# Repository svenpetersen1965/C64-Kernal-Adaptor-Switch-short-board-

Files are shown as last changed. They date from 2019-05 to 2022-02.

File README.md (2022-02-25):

# C64-Kernal-Adapter-Switch-short-board-
This is a Kernal Adapter/Switch for the Commodore C64, ASSY250469 (short board). 
Since the BASIC is stored in the same ROM, some circuit is required to allow a stable access to BASIC, while the Kernal can be selected.
The kernal selection can be configured with jumpers, a switch or even with a micro controller. +5V are provided on the pin header for this purpose.

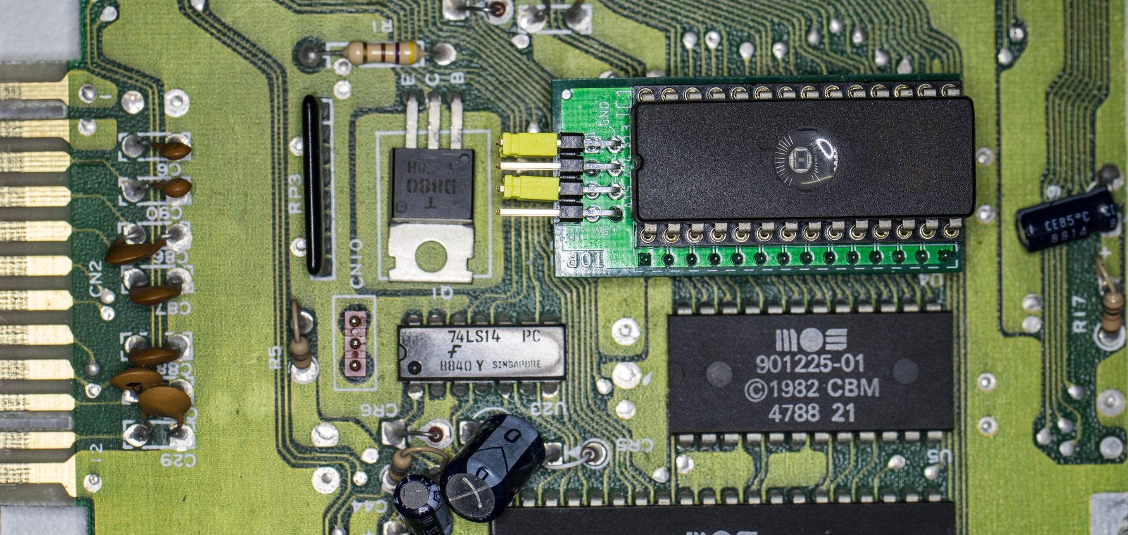
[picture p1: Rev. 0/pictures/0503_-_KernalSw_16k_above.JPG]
C64 kernal adapter/switch for ASSY250469


This development was inspired by Adrian Black's youtube video <a href="https://youtu.be/GPq5xnJRw2w">How-To: C64 Arduino based Restore Key/Four Kernal Switcher/Hard Reset</a>
# Rev. 2
Rev. 2 provides an optional pin heaer  with the address bit A5 and A8 for stereo SID applications
# BOM Calculation
The component prices of BOM v0.0 were summed up. The total is  4.88€, which does not include any shipping fees.

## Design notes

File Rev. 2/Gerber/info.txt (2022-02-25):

      
       Board: C64_KernalSw_16k
       Rev.:  2
  
       Files:
       ======
  
       All Gerber files are generated in extended gerber format (RS274X)
       *.TOP        : Film top copper
       *.BOT        :  -"- bottom copper
       *.STC        :  -"- top soldermask 
       *.STS        :  -"- bottom soldermask
       *.PLC        :  -"- silk screen top
       *.PLS        :  -"- silk screen bottom
       *.CRC        :  -"- cream top
       *.DK         : Drills plated Through (Excellon)
       *.NDK        : Drills not plated Through (Excellon)
       *.OUT        : Board outline

       Board Size:
       ===========
       Length     :   45.0 mm
       Width      :   22.0 mm
       Thickness  :   1.6 mm
       Material   :   FR 4
       Copper     :   35 um
       Surface    :   HASL
       
       Remarks:
       ========

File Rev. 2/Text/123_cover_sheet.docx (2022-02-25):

Project Documentation

C64 Kernal Adapter/Switch (Short Board)

Project number: 123

Revision: 2

Date: 14.11.2021

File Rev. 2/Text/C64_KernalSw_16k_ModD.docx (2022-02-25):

C64 Kernal Adapter/Switch (Short Board) Rev. 2

Module Description

# Introduction

The board serves for adapting the BASIC/KERNAL ROM U4 (type 23128b) to a 27C512 (or 27C256 or 27C128) EPROM. The pin out of both ICs are slightly different and need adaptation. Furthermore, it allows to access (up to 7) different kernals, which can be selected via the pin-header on the module.

This pin-header is connected in a way, that the selection can either be accomplished with standard 2.54mm jumper bridges, DIP-switches, hex-encoding switches or a microcontroller like an Arduino etc.

Signal | Pin | Pin | Signal
A13 | 1 | 2 | GND
A14 | 3 | 4 | GND
A15 | 5 | 6 | GND
+5V | 7 | 8 | n.c.

Table 1: Jumper (JP1) for Bank Selection

The +5V pins are to provide supply voltage to a microcontroller.

# Dimensions

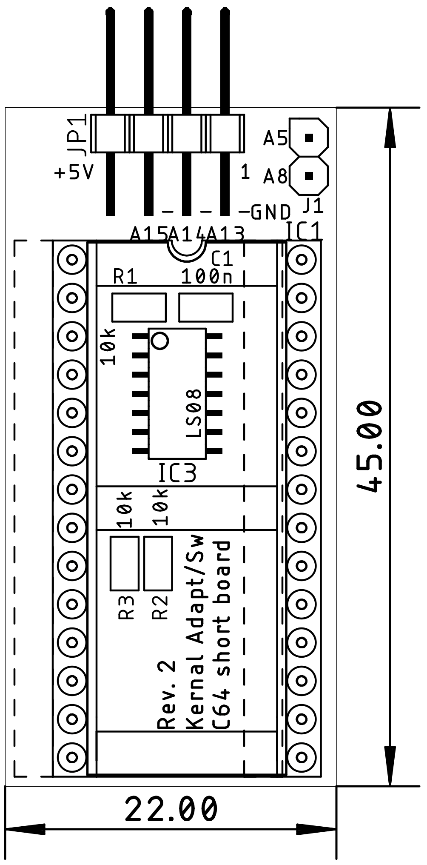
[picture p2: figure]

Figure 1: Kernal Adapter/Switch

# Function

The short board (ASSY 250469) stores the BASIC and the KERNAL in the same ROM. Long boards (all earlier ASSYs) have a separate ROM for BASIC.

The BASIC is located in the C64’s address space between 0xA000 - 0xBFFF, the KERNAL is located between 0xE000 – 0xFFFF. The highest three address bits have to be taken care to distinguish between BASIC and KERNAL.

Hex Digit | Binary [A15…A12] | ROM
AHEX | HLHL | BASIC
BHEX | HLHH | BASIC
EHEX | HHHL | KERNAL
FHEX | HHHH | KERNAL

Table 2: Encoding of the address bits

A15, A13 and A12 are encoded the same was for both the BASIC and the KERNAL. A14 makes the difference. Consulting the schematic of ASSY250469 (Document 252312), A14 of the CPU address bus is connected to A13 (pin 26) of the 16k ROM (U4/23128B). A LOW on A14 will select the lower 8k, a HIGH will select the higher 8k.

This has to be taken care of on the EPROM adapter. A LOW on A13 (which is connected to A14 of the CPU) has to select the lowest (BASIC) 8k block, a HIGH is addressing the (KERNAL) 8k memory block, which is selected by the jumper JP1. The trick is done with three AND gates (IC3). The outputs are connected to A13 … A15 of the EPROM. One input of each one is connected to pin 26 of the socket U4. In case this is LOW (BASIC selected) the output of all three gates is LOW, too. The lowest 8k memory block of the EPROM is selected. In case pin 26 is HIGH, the configuration set on JP1 appears at the output of the AND gates. This way, the selected 8k memory block of the EPROM is addressed.

# Bank Selection

The desired KERNAL is selected at JP1. For the pinout refer to Table 1. The jumper is installed (vertically) in a way, that it connects the address line with the GND potential.

A15 | A14 | A13 | 8k Block | Addr. Offset
set | set | set | illegal | 0x0000
set | set | open | #1 | 0x2000
set | open | set | #2 | 0x4000
set | open | open | #3 | 0x6000
open | set | set | #4 | 0x8000
open | set | open | #5 | 0xA000
open | open | set | #6 | 0xC000
open | open | open | #7 | 0xE000

Table 3: Selection of EPROM memory blocks

A set jumper corresponds to a LOW level (binary 0), an open jumper to a HIGH level. Do not confuse the C64 memory address and the EPROM memory address. They have the address Bit A0 to A12 in common, but the rest is different. Each of the 8k blocks appears between address $E000 and $FFFF of the C64. The setting marked illegal selects the lowest 8k, which are reserved for the BASIC. Do not use more than two jumpers to prevent this.

# Sources for BASIC and KERNAL

The content of the BASIC ROM and the KERNAL ROM can be found here:

http://www.zimmers.net/anonftp/pub/cbm/firmware/computers/c64/index.html (64c.251913-01.bin (http://www.zimmers.net/anonftp/pub/cbm/firmware/computers/c64/64c.251913-01.bin))

This file includes the BASIC and the original KERNAL and have to be loaded to the lowest 16k of the EPROM. In case it is not desired to load the original KERNAL to 8k-Block #1, this memory block can be overwritten.

Separate BASIC and KERNAL ROMs and Scandinavian KERNAL ROMs can be found at the URL mentioned before or can alternatively be obtained from the Emulator Software VICE (C64/basic and C64/kernal).

Alternative kernals can be found elsewhere on internet. A reliable source is

https://csdb.dk/

The popular JiffyDOS is still a commercial product and can be acquired for little money from

http://www.go4retro.com/

JaffyDOS is a patch for JiffyDOS. The patch program can be obtained from World of Jani:

http://blog.worldofjani.com

# Setting up an EPROM image

Combining the desired ROM (*.bin) files to one programming image works with the software of the programmer. This might a different with different model. Here it is demonstrated using the popular TL866. In case the programmer software does not provide the function, a Hex Editor like HxD will do the job.

First, the BASIC ROM has to be loaded into the buffer. This works like always:

File → Open → Select the BASIC ROM

Use default file load options (Figure 2):

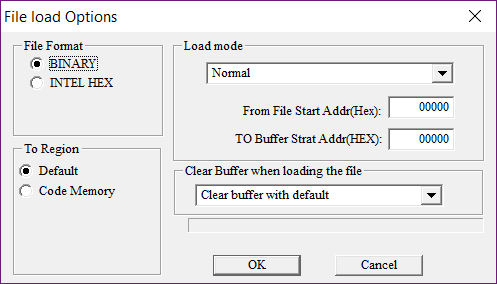
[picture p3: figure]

Figure 2: Default load options, clear buffer with default

Now the BASIC is loaded. It will occupy the addresses 0000 – 1FFF.

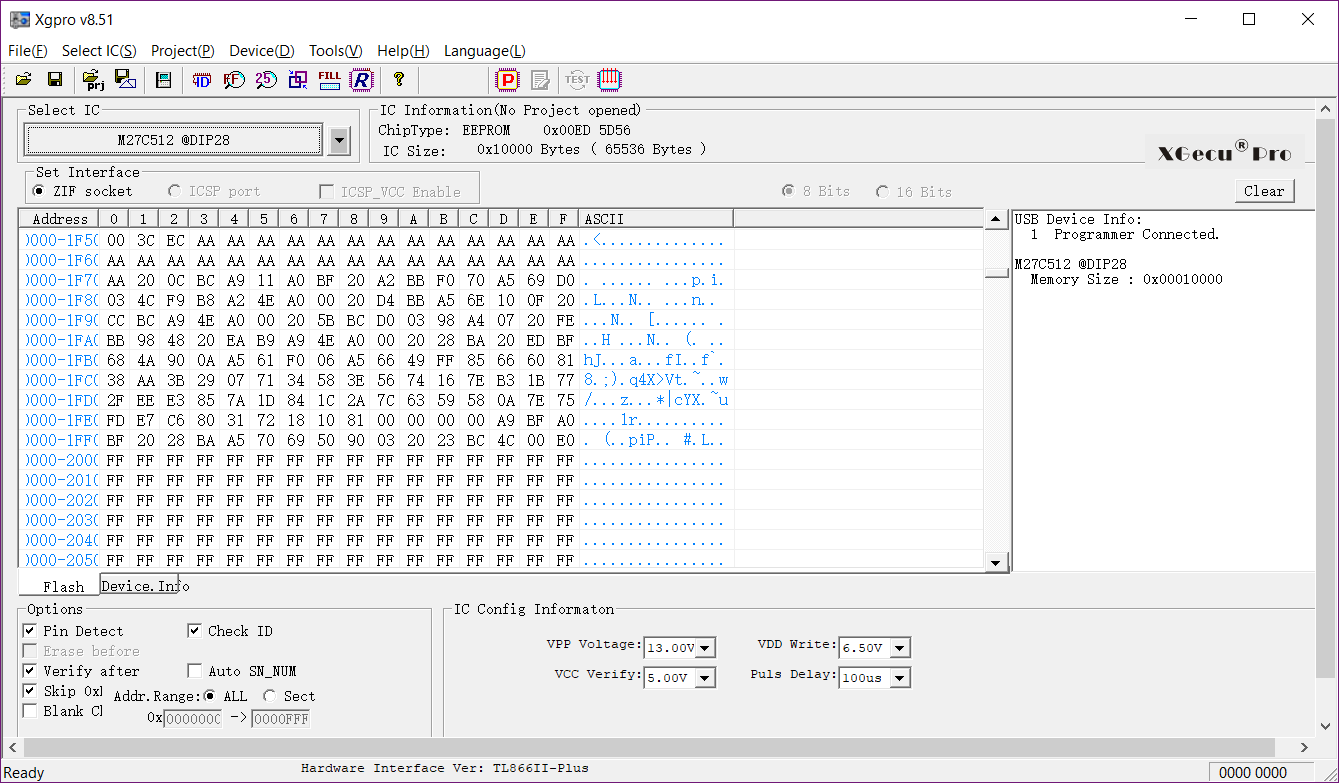
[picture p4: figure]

Figure 3: Buffer content after BASIC was loaded

The buffer above 1FFF is still empty (filled with FF, Figure 3).

The KERNAL has to be loaded to the next free 8k memory block in the buffer. Please refer to Table 3. Further, it is important, not to clear the buffer. Otherwise, the BASIC will be lost and the EPROM will not work. Refer to Figure 4.

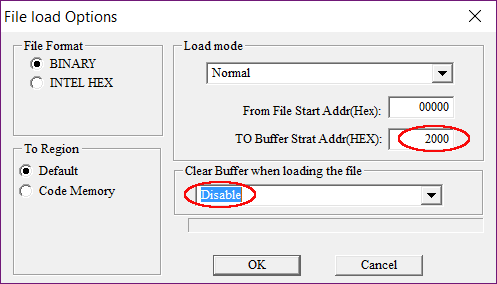
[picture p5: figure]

Figure 4: Load options for the first KERNAL

Clear Buffer when loading file is disabled, the address for the first kernal is 2000HEX

Repeat this procedure with the appropriate buffer/EPROM address, until all desired kernals are in the buffer. Store the buffer for later use, insert a blank EPROM and program it. Insert it in the Kernal Adapter/Switch.

# Adding More Kernals to an Already programmed EPROM

In case the unused 8k memory slots of the EPROM are filled with FF, it is still possible to program additional kernel images without erasing them before. FF is the content of an empty byte in an EPROM. It is possible to alter such a byte to every other byte content. Before the new memory is written, the prior content can be read into the program buffer, then a free 8k slot is determined and the kernel is loaded into that slot. Refer to chapter “Setting up an EPROM image”. Now, the buffer content can be programmed. It is possible to program the complete buffer, the bytes already programmed will (usually) not be corrupted and after programming, the EPROM will verify ok.

# Installation

Possibly, the BASIC/Kernal ROM (U4) has to be unsoldered and a socket (preferably round pin precision contacts) has to be installed, before the Kernal Adapter/Switch can be installed on ASSY250469. The notch of the EPROM is pointing towards the user port, when installed properly (Figure 5).

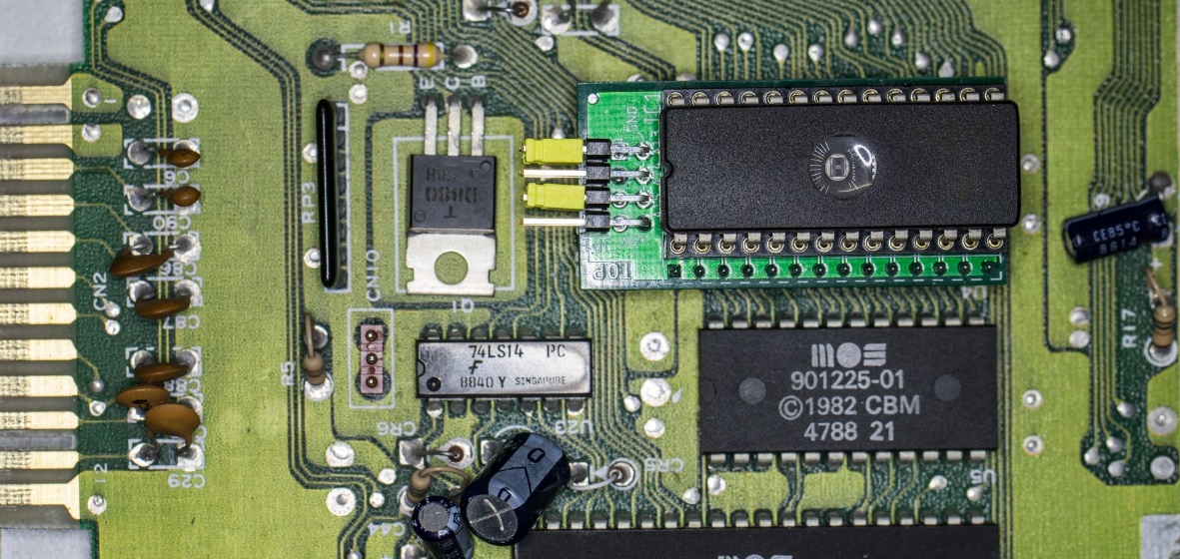
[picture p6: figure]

Figure 5: Installation of the Kernal Adapter/Switch

Usually, the board fits above the components placed next to U4, maybe those have to be bent backwards a bit. Prevent that the resistor touches the pin header of the adapter under all circumstances.

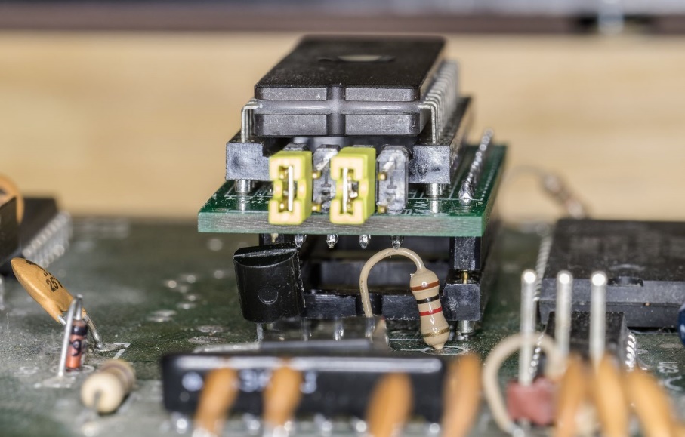
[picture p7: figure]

Figure 6: Parts under the adapter board

# Compatibility of EPROMs

It is recommended to use 27C512 EPROMs only. The smaller EPROM Types 27C256 and 27C128 might conflict with accessing the BASIC 8k slot. The unused address signals will be tied LOW while this access. This means, that Vpp will be approximately 0V and /PGM will be low. This is a not recommended setting.

27C128
| 27C256
| | 27C512
| | | SOCKET
Vpp | Vpp | A15 | 1 | A15 | VCC | 28 | VCC | VCC | VCC
A12 | A12 | A12 | 2 | A12 | A14 | 27 | A14 | A14 | /PGM
A7 | A7 | A7 | 3 | A7 | A13 | 26 | A13 | A13 | A13
A6 | A6 | A6 | 4 | A6 | A8 | 25 | A8 | A8 | A8
A5 | A5 | A5 | 5 | A5 | A9 | 24 | A9 | A9 | A9
A4 | A4 | A4 | 6 | A4 | A11 | 23 | A11 | A11 | A11
A3 | A3 | A3 | 7 | A3 | /OE | 22 | /G/Vpp | /G | /G
A2 | A2 | A2 | 8 | A2 | A10 | 21 | A10 | A10 | A10
A1 | A1 | A1 | 9 | A1 | GND | 20 | /E | /E | /E
A0 | A0 | A0 | 10 | A0 | D7 | 19 | D7 | D7 | D7
D0 | D0 | D0 | 11 | D0 | D6 | 18 | D6 | D6 | D6
D1 | D1 | D1 | 12 | D1 | D5 | 17 | D5 | D5 | D5
D2 | D2 | D2 | 13 | D2 | D4 | 16 | D4 | D4 | D4
GND | GND | GND | 14 | GND | D3 | 15 | D3 | D3 | D3

Table 4: EPROM pin compatibility

# Startup and Trouble shooting

Before you insert the Kernal Adaptor/Switch into the socket of U4, you should make sure, that there are no fatal failures on it. In the worst case, it will produce a short circuit.

- Check the solder joints on the solder side
- Check the orientation of the socket. The notch is oriented to the side, where the jumper is located
- Make sure, that no jumper is installed horizontally. This could connect GND and VCC, which is a short circuit.
- After inserting the EPROM, check if the notch is at the same side like the notch of the socket. Check all pins are properly seated in the socket and not bent inwards or outwards.

After all these points are correct, nothing really bad can happen to your C64 anymore. If you get a black screen you only have a configuration problem.

- Did you program the EPROM with a proper *.bin file? BASIC and one or more kernals? Maybe check the buffer content of your programmer software again.
- Did you set the address bits A13…A15 correctly? A set (closed) jumper means LOW
- You must not set all jumpers. This would put the BASIC in place of the Kernal, which will not work.

# Revision History

## Rev. 0

- Fully working prototype

## Rev. 1

- The shape of the solder-pads of JP1 was changed to enable bridging. Pin 10 is not connected to +5V anymore.

## Rev. 2

- J1 provides A8 and A5 for stereo SID applications

C64_KernalSw_16k_ModD.docx 25.02.2022 10:36 Drafted by Sven Petersen Page 2 of 2 Doc.-No.: 123-6-01-02

C64_KernalSw_16k_ModD.docx 25.02.2022 10:36 Drafted by Sven Petersen Page 1 of 1 Doc.-No.: 123-6-01-00

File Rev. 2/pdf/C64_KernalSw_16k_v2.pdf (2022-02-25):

# Project Documentation

## C64 Kernal Adapter/Switch (Short Board)

## Project number: 123

## Revision: 2

## Date: 14.11.2021

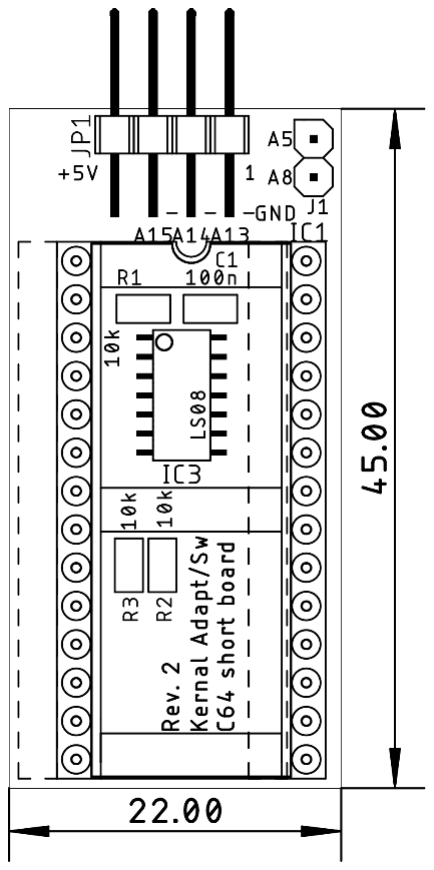
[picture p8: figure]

C64_KernalSw_16k_ModD.docx | | 25.02.2022 10:36
Drafted by Sven Petersen | Page 1 of 7 | Doc.-No.: 123-6-01-02

### C64 Kernal Adapter/Switch (Short Board) Rev. 2

### Module Description

## Introduction

The board serves for adapting the BASIC/KERNAL ROM U4 (type 23128b) to a 27C512 (or 27C256 or 27C128) EPROM. The pin out of both ICs are slightly different and need adaptation. Furthermore, it allows to access (up to 7) different kernals, which can be selected via the pin-header on the module.

This pin-header is connected in a way, that the selection can either be accomplished with standard 2.54mm jumper bridges, DIP-switches, hex-encoding switches or a microcontroller like an Arduino etc.

Signal Pin | Pin Signal
A13 | 1 | 2 | GND
A14 | 3 | 4 | GND
A15 | 5 | 6 | GND
+5V | 7 | 8 | n.c.
Table 1: Jumper (JP1) for Bank Selection

The +5V pins are to provide supply voltage to a microcontroller.

## Dimensions

Figure 1: Kernal Adapter/Switch

## Function

The short board (ASSY 250469) stores the BASIC and the KERNAL in the same ROM. Long boards (all earlier ASSYs) have a separate ROM for BASIC.

C64_KernalSw_16k_ModD.docx | | 25.02.2022 10:36
Drafted by Sven Petersen | Page 2 of 7 | Doc.-No.: 123-6-01-02

### The BASIC is located in the C64’s address space between 0xA000 - 0xBFFF, the KERNAL is

located between 0xE000 – 0xFFFF. The highest three address bits have to be taken care to distinguish between BASIC and KERNAL.
Hex Digit | Binary [A15…A12] ROM
AHEX | HLHL | BASIC
BHEX | HLHH | BASIC
EHEX | HHHL | KERNAL
FHEX | HHHH | KERNAL
Table 2: Encoding of the address bits

A15, A13 and A12 are encoded the same was for both the BASIC and the KERNAL. A14 makes the difference. Consulting the schematic of ASSY250469 (Document 252312), A14 of the CPU address bus is connected to A13 (pin 26) of the 16k ROM (U4/23128B). A LOW on A14 will select the lower 8k, a HIGH will select the higher 8k.

This has to be taken care of on the EPROM adapter. A LOW on A13 (which is connected to A14 of the CPU) has to select the lowest (BASIC) 8k block, a HIGH is addressing the (KERNAL) 8k memory block, which is selected by the jumper JP1. The trick is done with three AND gates (IC3). The
outputs are connected to A13 … A15 of the EPROM. One input of each one is connected to pin
26 of the socket U4. In case this is LOW (BASIC selected) the output of all three gates is LOW, too. The lowest 8k memory block of the EPROM is selected. In case pin 26 is HIGH, the configuration set on JP1 appears at the output of the AND gates. This way, the selected 8k memory block of the EPROM is addressed.

## Bank Selection

The desired KERNAL is selected at JP1. For the pinout refer to Table 1. The jumper is installed (vertically) in a way, that it connects the address line with the GND potential.

A15 | A14 | A13 | 8k Block | Addr. Offset
set | set | set | illegal | 0x0000
set | set | open | #1 | 0x2000
set | open | set | #2 | 0x4000
set | open | open | #3 | 0x6000
open | set | set | #4 | 0x8000
open | set | open | #5 | 0xA000
open | open | set | #6 | 0xC000
open | open | open | #7 | 0xE000
Table 3: Selection of EPROM memory blocks

A set jumper corresponds to a LOW level (binary 0), an open jumper to a HIGH level. Do not confuse the C64 memory address and the EPROM memory address. They have the address Bit A0 to A12 in common, but the rest is different. Each of the 8k blocks appears between address $E000 and $FFFF of the C64. The setting marked illegal selects the lowest 8k, which are reserved for the BASIC. Do not use more than two jumpers to prevent this.

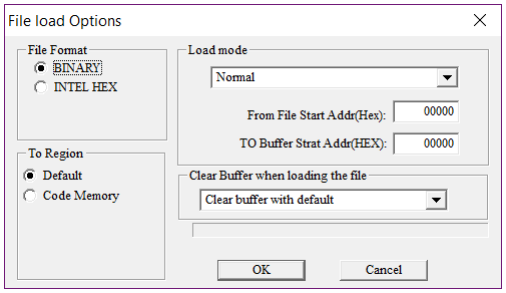
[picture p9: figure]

C64_KernalSw_16k_ModD.docx | | 25.02.2022 10:36
Drafted by Sven Petersen | Page 3 of 7 | Doc.-No.: 123-6-01-02

## Sources for BASIC and KERNAL

The content of the BASIC ROM and the KERNAL ROM can be found here:

http://www.zimmers.net/anonftp/pub/cbm/firmware/computers/c64/index.html (64c.251913-01.bin) (http://www.zimmers.net/anonftp/pub/cbm/firmware/computers/c64/64c.251913-01.bin)

This file includes the BASIC and the original KERNAL and have to be loaded to the lowest 16k of the EPROM. In case it is not desired to load the original KERNAL to 8k-Block #1, this memory block can be overwritten.

Separate BASIC and KERNAL ROMs and Scandinavian KERNAL ROMs can be found at the URL mentioned before or can alternatively be obtained from the Emulator Software VICE (C64/basic and C64/kernal).

Alternative kernals can be found elsewhere on internet. A reliable source is

https://csdb.dk/

The popular JiffyDOS is still a commercial product and can be acquired for little money from

http://www.go4retro.com/

JaffyDOS is a patch for JiffyDOS. The patch program can be obtained from World of Jani:

http://blog.worldofjani.com

## Setting up an EPROM image

Combining the desired ROM (*.bin) files to one programming image works with the software of the programmer. This might a different with different model. Here it is demonstrated using the popular TL866. In case the programmer software does not provide the function, a Hex Editor like HxD will do the job.

First, the BASIC ROM has to be loaded into the buffer. This works like always:

File → Open → Select the BASIC ROM

Use default file load options (Figure 2):

Figure 2: Default load options, clear buffer with default
Now the BASIC is loaded. It will occupy the addresses 0000 – 1FFF.

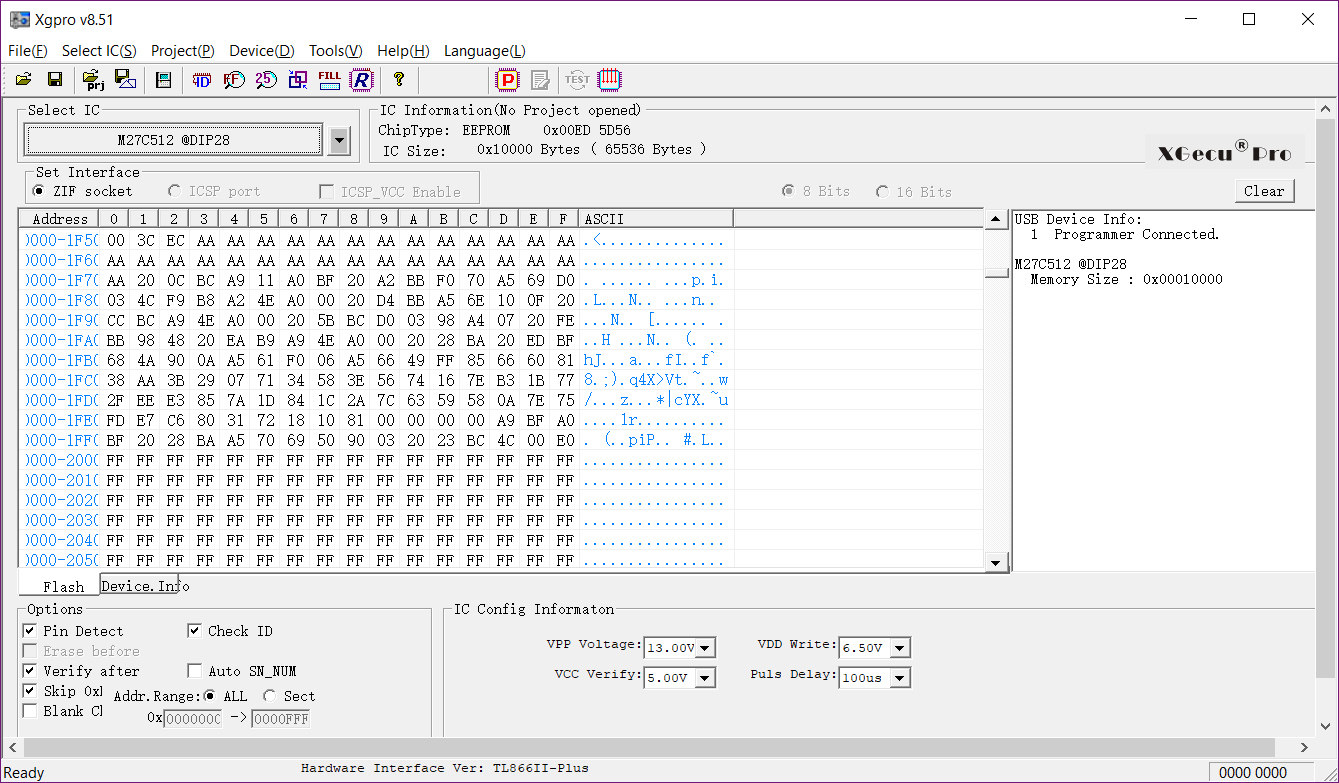
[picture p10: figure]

C64_KernalSw_16k_ModD.docx | | 25.02.2022 10:36
Drafted by Sven Petersen | Page 4 of 7 | Doc.-No.: 123-6-01-02

Figure 3: Buffer content after BASIC was loaded

The buffer above 1FFF is still empty (filled with FF, Figure 3).

The KERNAL has to be loaded to the next free 8k memory block in the buffer. Please refer to Table
3. Further, it is important, not to clear the buffer. Otherwise, the BASIC will be lost and the EPROM will not work. Refer to Figure 4.

Figure 4: Load options for the first KERNAL

Clear Buffer when loading file is disabled, the address for the first kernal is 2000HEX

Repeat this procedure with the appropriate buffer/EPROM address, until all desired kernals are in the buffer. Store the buffer for later use, insert a blank EPROM and program it. Insert it in the Kernal Adapter/Switch.

## Adding More Kernals to an Already programmed EPROM

In case the unused 8k memory slots of the EPROM are filled with FF, it is still possible to program additional kernel images without erasing them before. FF is the content of an empty byte in an EPROM. It is possible to alter such a byte to every other byte content. Before the new memory is written, the prior content can be read into the program buffer, then a free 8k slot is determined and the kernel is loaded into that slot. Refer to chapter “Setting up an EPROM image”. Now, the

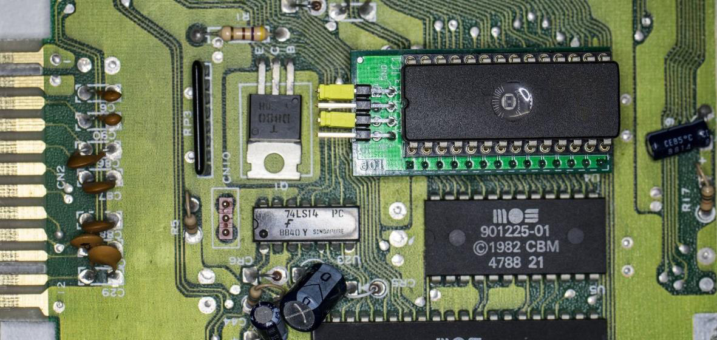
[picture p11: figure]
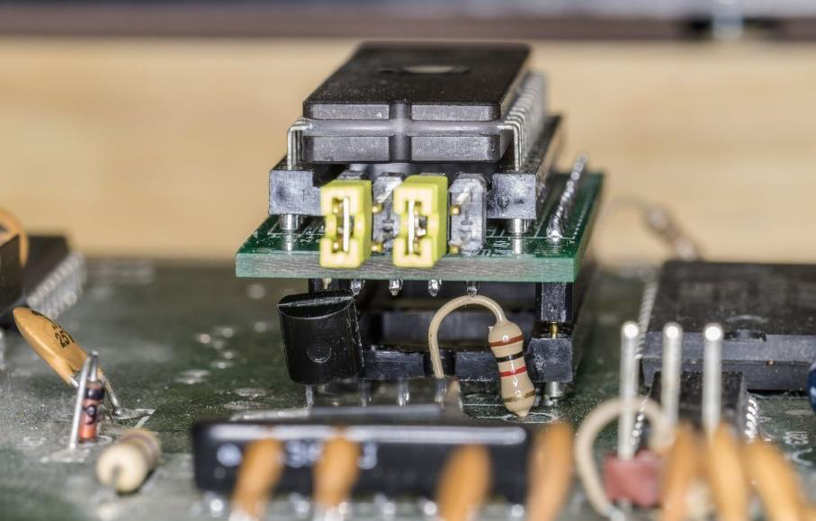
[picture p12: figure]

C64_KernalSw_16k_ModD.docx | | 25.02.2022 10:36
Drafted by Sven Petersen | Page 5 of 7 | Doc.-No.: 123-6-01-02

buffer content can be programmed. It is possible to program the complete buffer, the bytes already programmed will (usually) not be corrupted and after programming, the EPROM will verify ok.

## Installation

Possibly, the BASIC/Kernal ROM (U4) has to be unsoldered and a socket (preferably round pin precision contacts) has to be installed, before the Kernal Adapter/Switch can be installed on ASSY250469. The notch of the EPROM is pointing towards the user port, when installed properly (Figure 5).

Figure 5: Installation of the Kernal Adapter/Switch

Usually, the board fits above the components placed next to U4, maybe those have to be bent backwards a bit. Prevent that the resistor touches the pin header of the adapter under all circumstances.

Figure 6: Parts under the adapter board

## Compatibility of EPROMs

It is recommended to use 27C512 EPROMs only. The smaller EPROM Types 27C256 and 27C128 might conflict with accessing the BASIC 8k slot. The unused address signals will be tied

C64_KernalSw_16k_ModD.docx | | 25.02.2022 10:36
Drafted by Sven Petersen | Page 6 of 7 | Doc.-No.: 123-6-01-02

LOW while this access. This means, that Vpp will be approximately 0V and /PGM will be low. This is a not recommended setting.

27C128
| 27C256
| 27C512
| SOCKET
Vpp | Vpp | A15 | 1 | A15 | VCC | 28 | VCC | VCC | VCC
A12 | A12 | A12 | 2 | A12 | A14 | 27 | A14 | A14 | /PGM
A7 | A7 | A7 | 3 | A7 | A13 | 26 | A13 | A13 | A13
A6 | A6 | A6 | 4 | A6 | A8 | 25 | A8 | A8 | A8
A5 | A5 | A5 | 5 | A5 | A9 | 24 | A9 | A9 | A9
A4 | A4 | A4 | 6 | A4 | A11 | 23 | A11 | A11 | A11
A3 | A3 | A3 | 7 | A3 | /OE | 22 | /G/Vpp | /G | /G
A2 | A2 | A2 | 8 | A2 | A10 | 21 | A10 | A10 | A10
A1 | A1 | A1 | 9 | A1 | GND | 20 | /E | /E | /E
A0 | A0 | A0 | 10 | A0 | D7 | 19 | D7 | D7 | D7
D0 | D0 | D0 | 11 | D0 | D6 | 18 | D6 | D6 | D6
D1 | D1 | D1 | 12 | D1 | D5 | 17 | D5 | D5 | D5
D2 | D2 | D2 | 13 | D2 | D4 | 16 | D4 | D4 | D4
GND | GND | GND | 14 | GND | D3 | 15 | D3 | D3 | D3
Table 4: EPROM pin compatibility

## Startup and Trouble shooting

Before you insert the Kernal Adaptor/Switch into the socket of U4, you should make sure, that there are no fatal failures on it. In the worst case, it will produce a short circuit.

- Check the solder joints on the solder side
- Check the orientation of the socket. The notch is oriented to the side, where the jumper is located
- Make sure, that no jumper is installed horizontally. This could connect GND and VCC, which is a short circuit.
- After inserting the EPROM, check if the notch is at the same side like the notch of the socket. Check all pins are properly seated in the socket and not bent inwards or outwards.

After all these points are correct, nothing really bad can happen to your C64 anymore. If you get a black screen you only have a configuration problem.

- Did you program the EPROM with a proper *.bin file? BASIC and one or more kernals? Maybe check the buffer content of your programmer software again.
- Did you set the address bits A13…A15 correctly? A set (closed) jumper means LOW
- You must not set all jumpers. This would put the BASIC in place of the Kernal, which will not work.

## Revision History

### Rev. 0

- Fully working prototype

C64_KernalSw_16k_ModD.docx | | 25.02.2022 10:36
Drafted by Sven Petersen | Page 7 of 7 | Doc.-No.: 123-6-01-02

### Rev. 1

- The shape of the solder-pads of JP1 was changed to enable bridging. Pin 10 is not connected to +5V anymore.

### Rev. 2

- J1 provides A8 and A5 for stereo SID applications

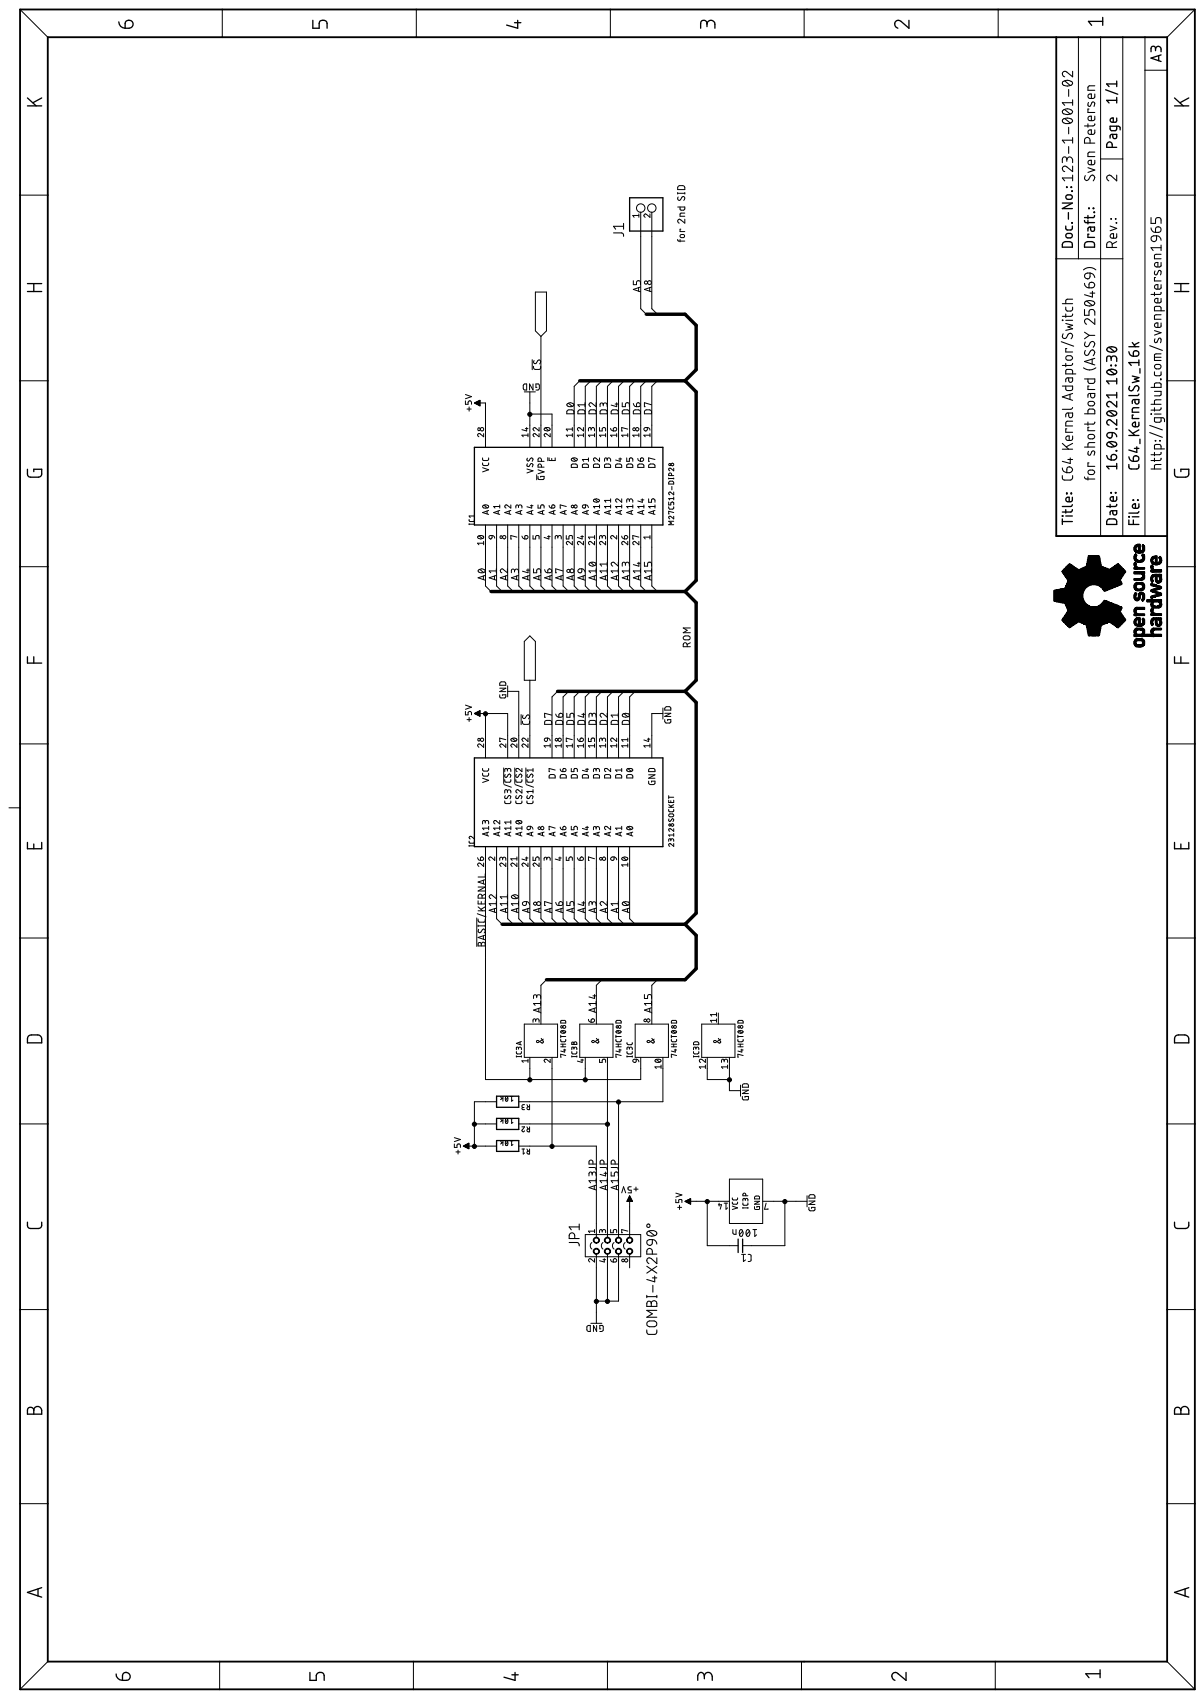
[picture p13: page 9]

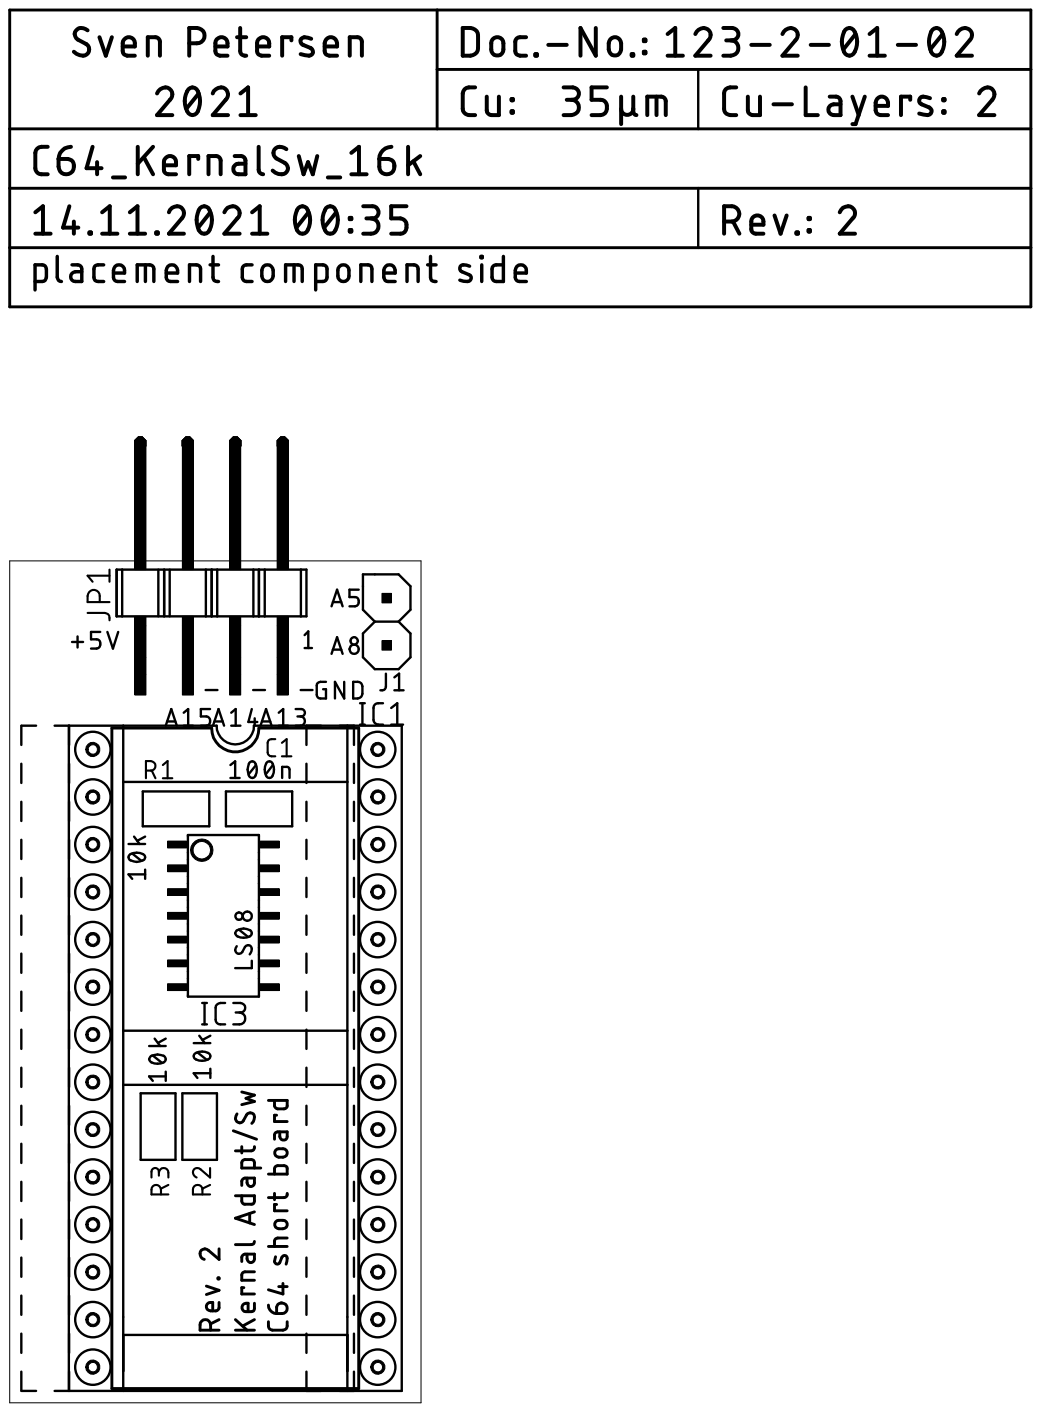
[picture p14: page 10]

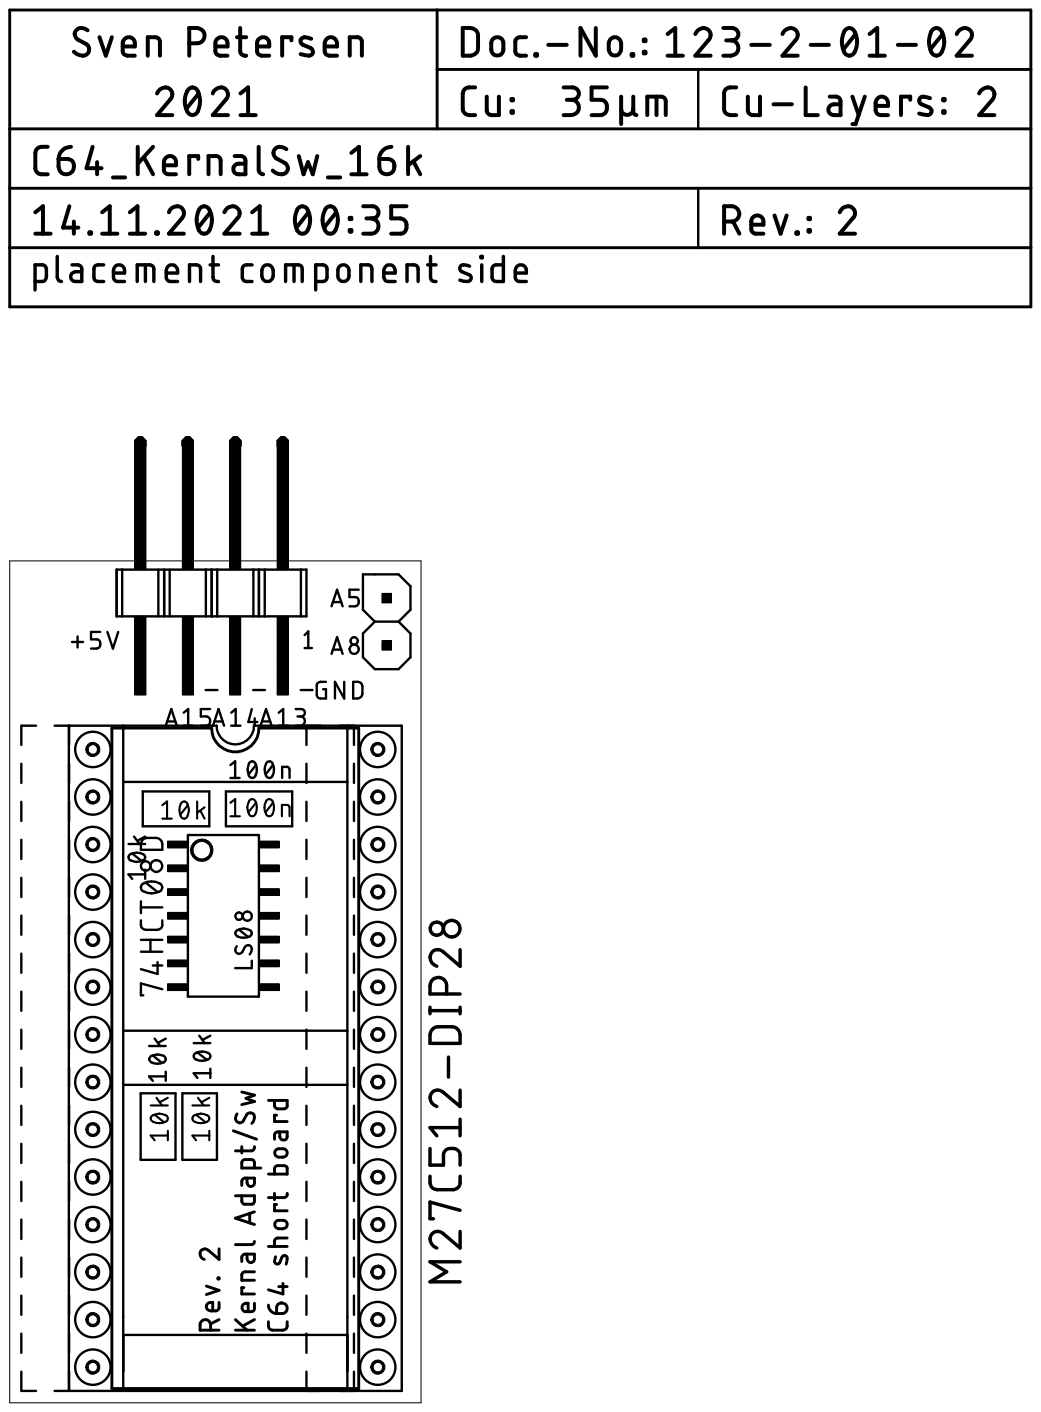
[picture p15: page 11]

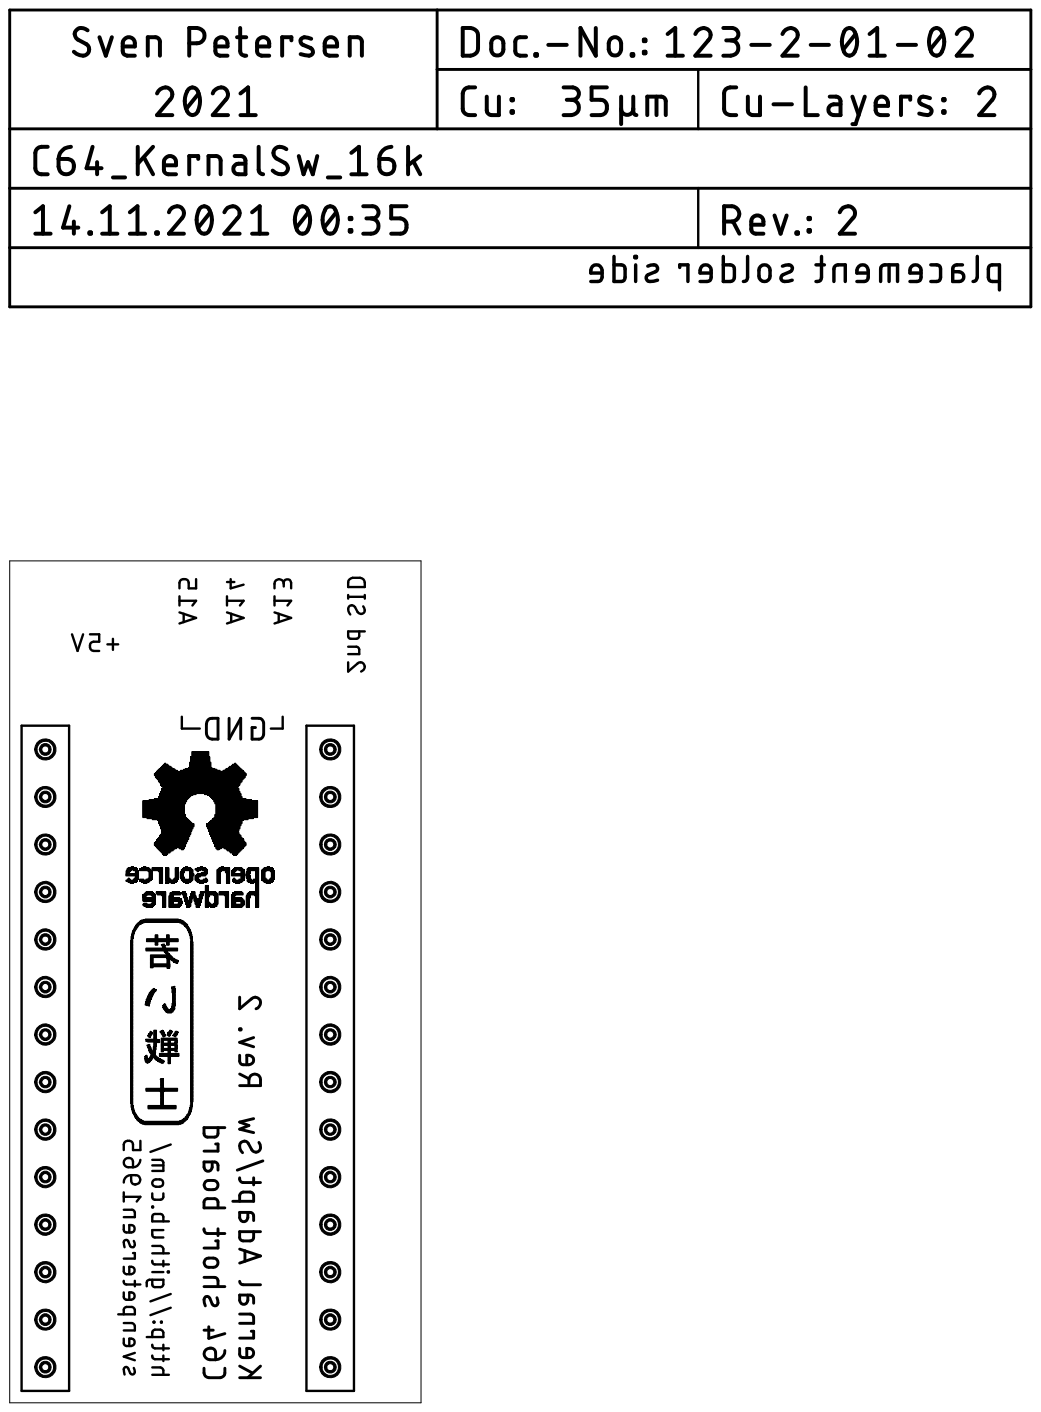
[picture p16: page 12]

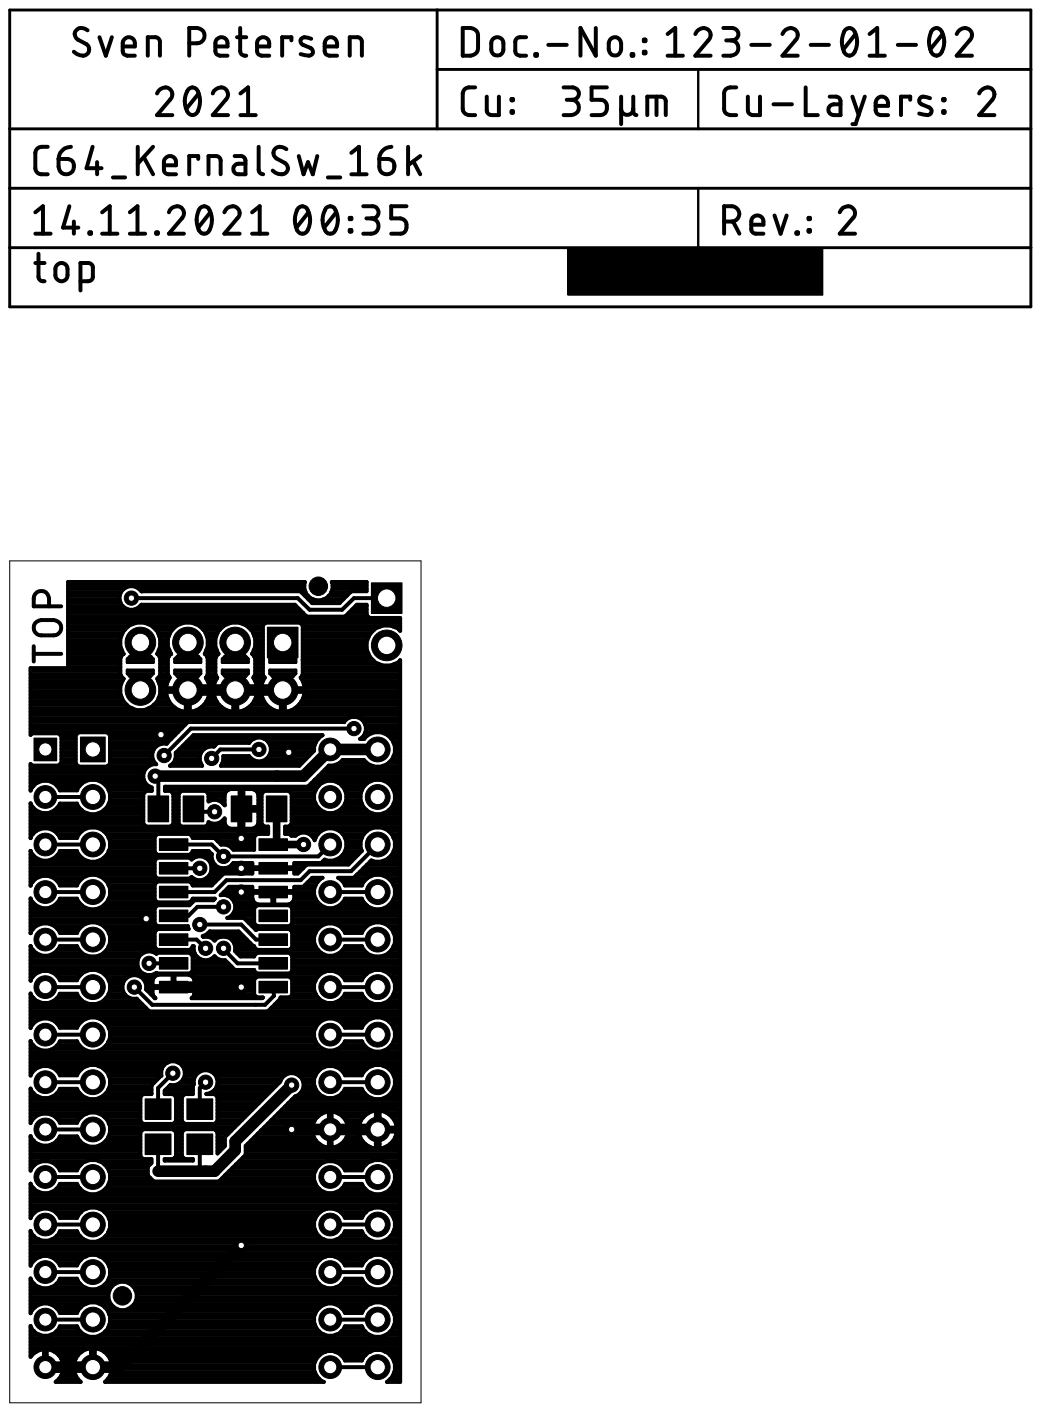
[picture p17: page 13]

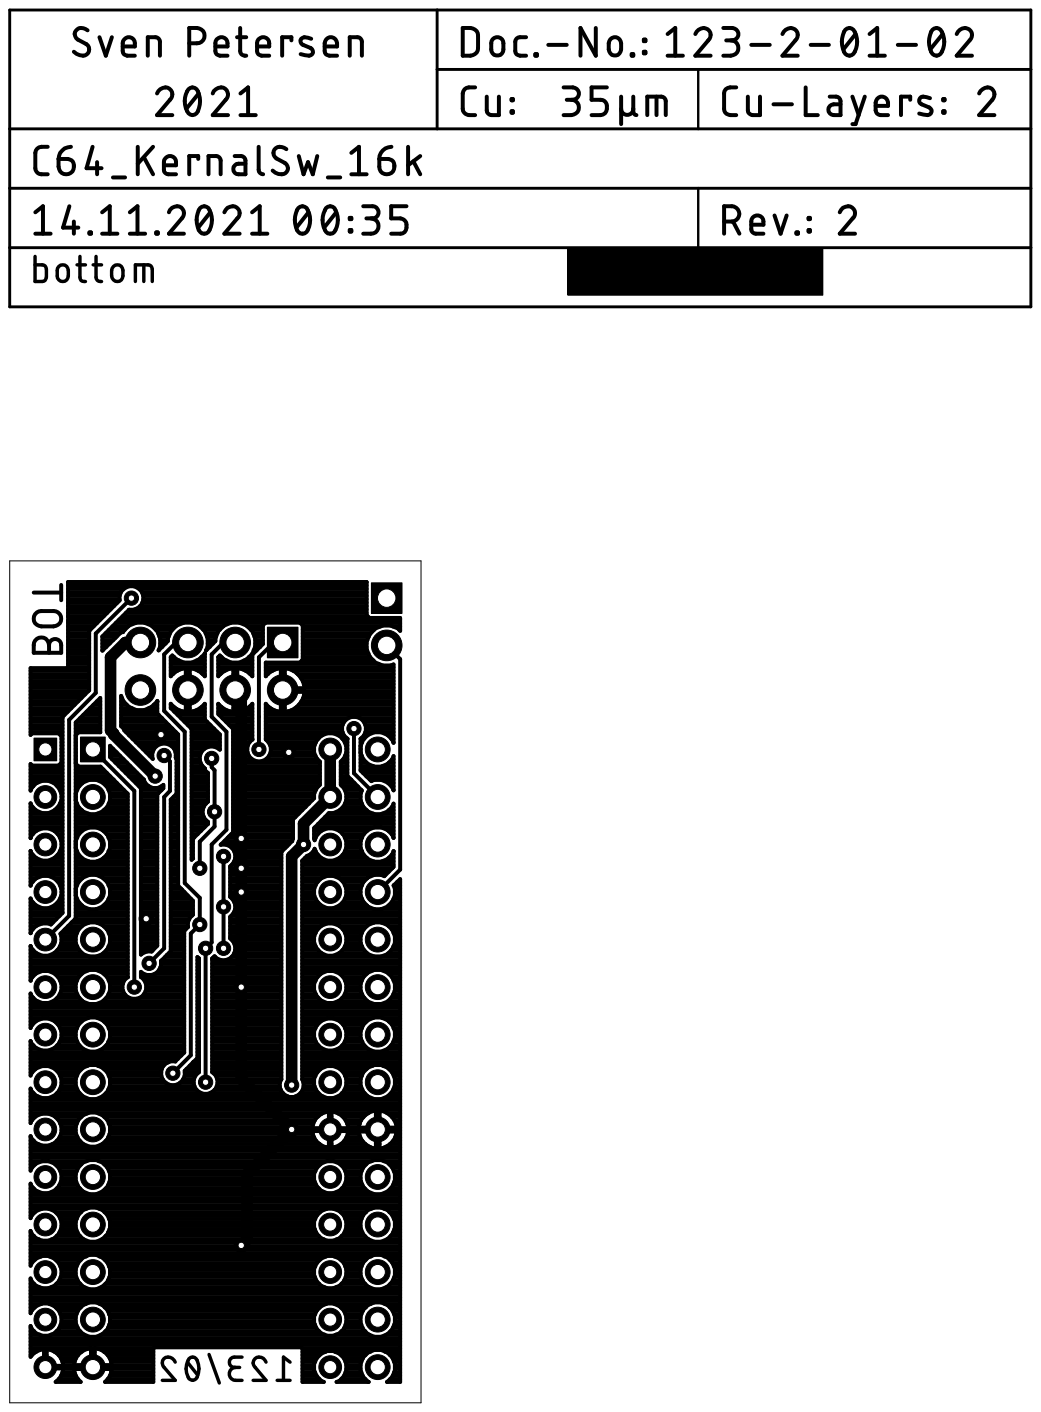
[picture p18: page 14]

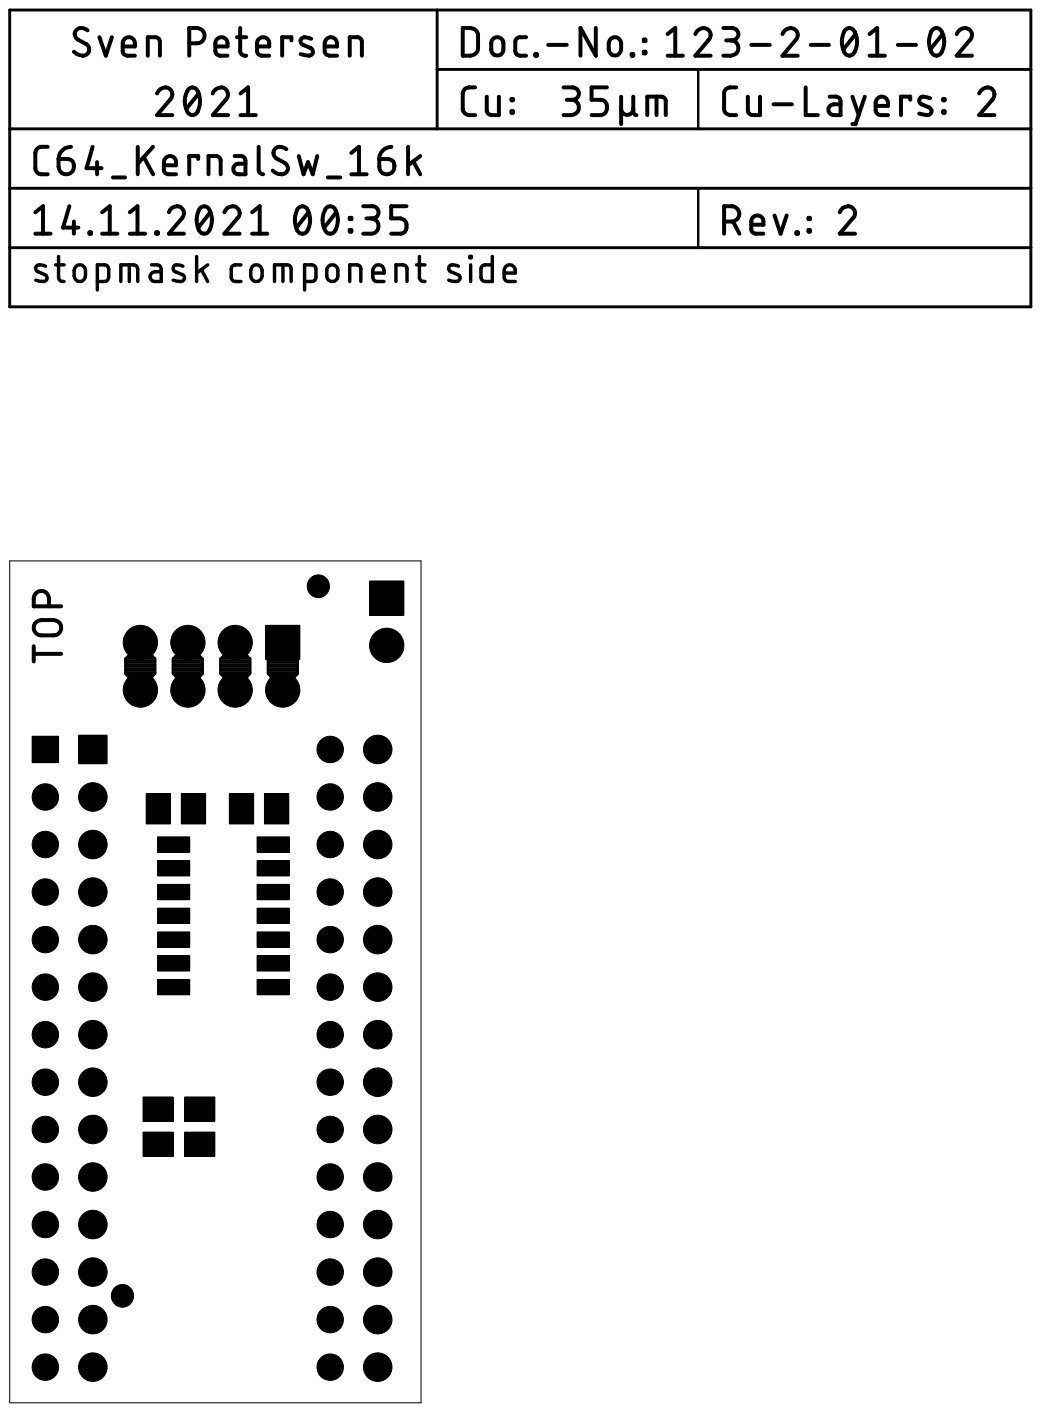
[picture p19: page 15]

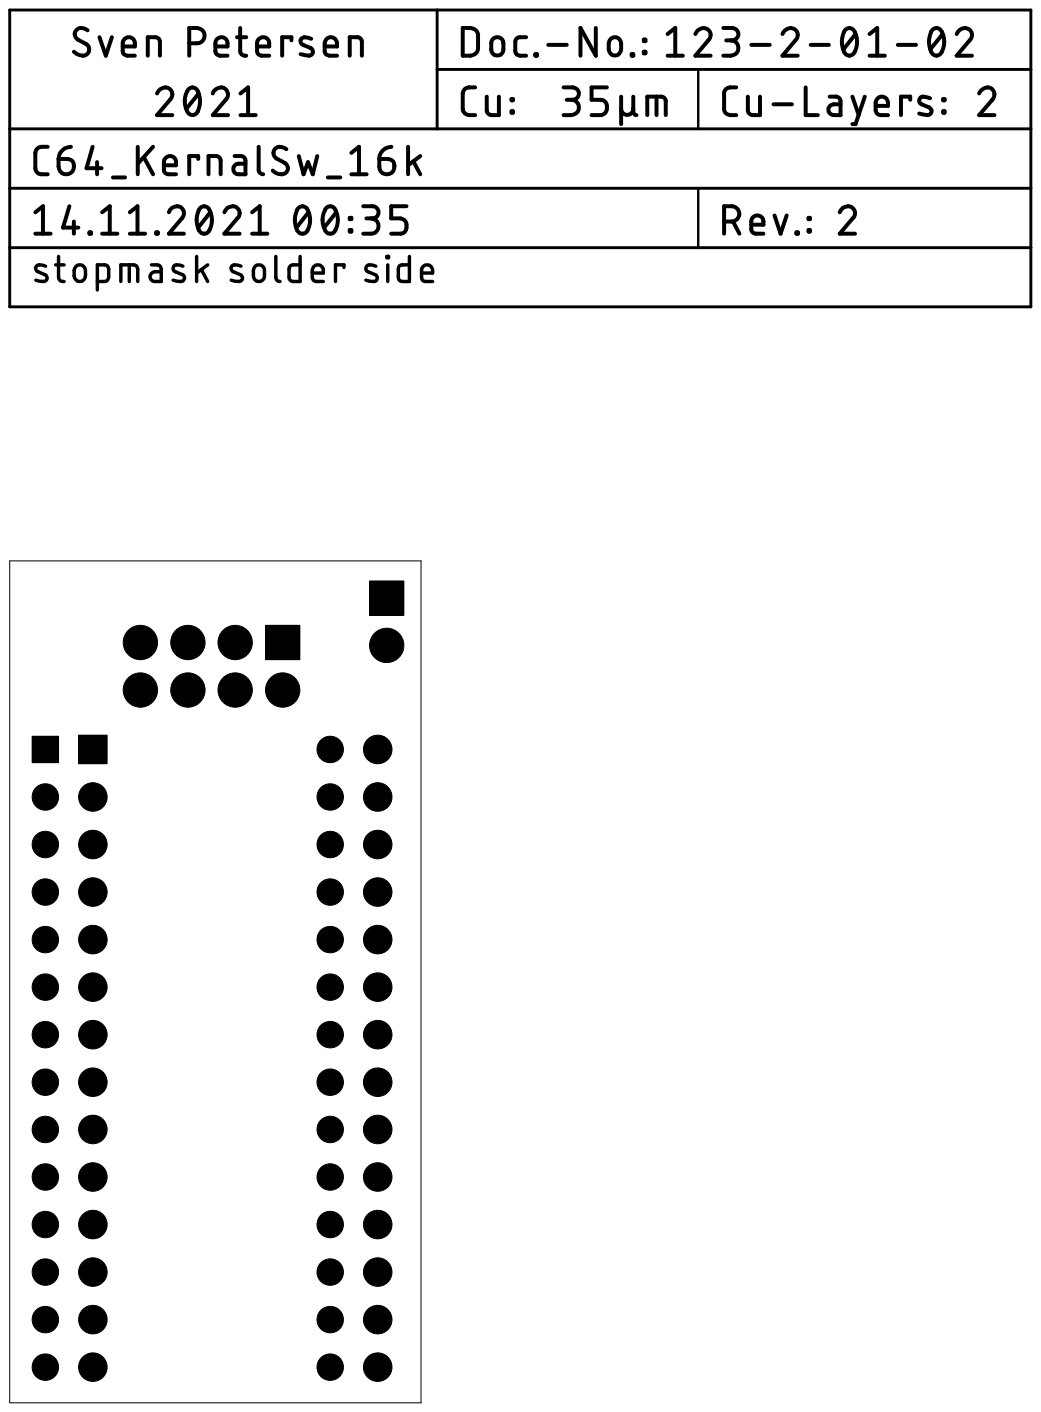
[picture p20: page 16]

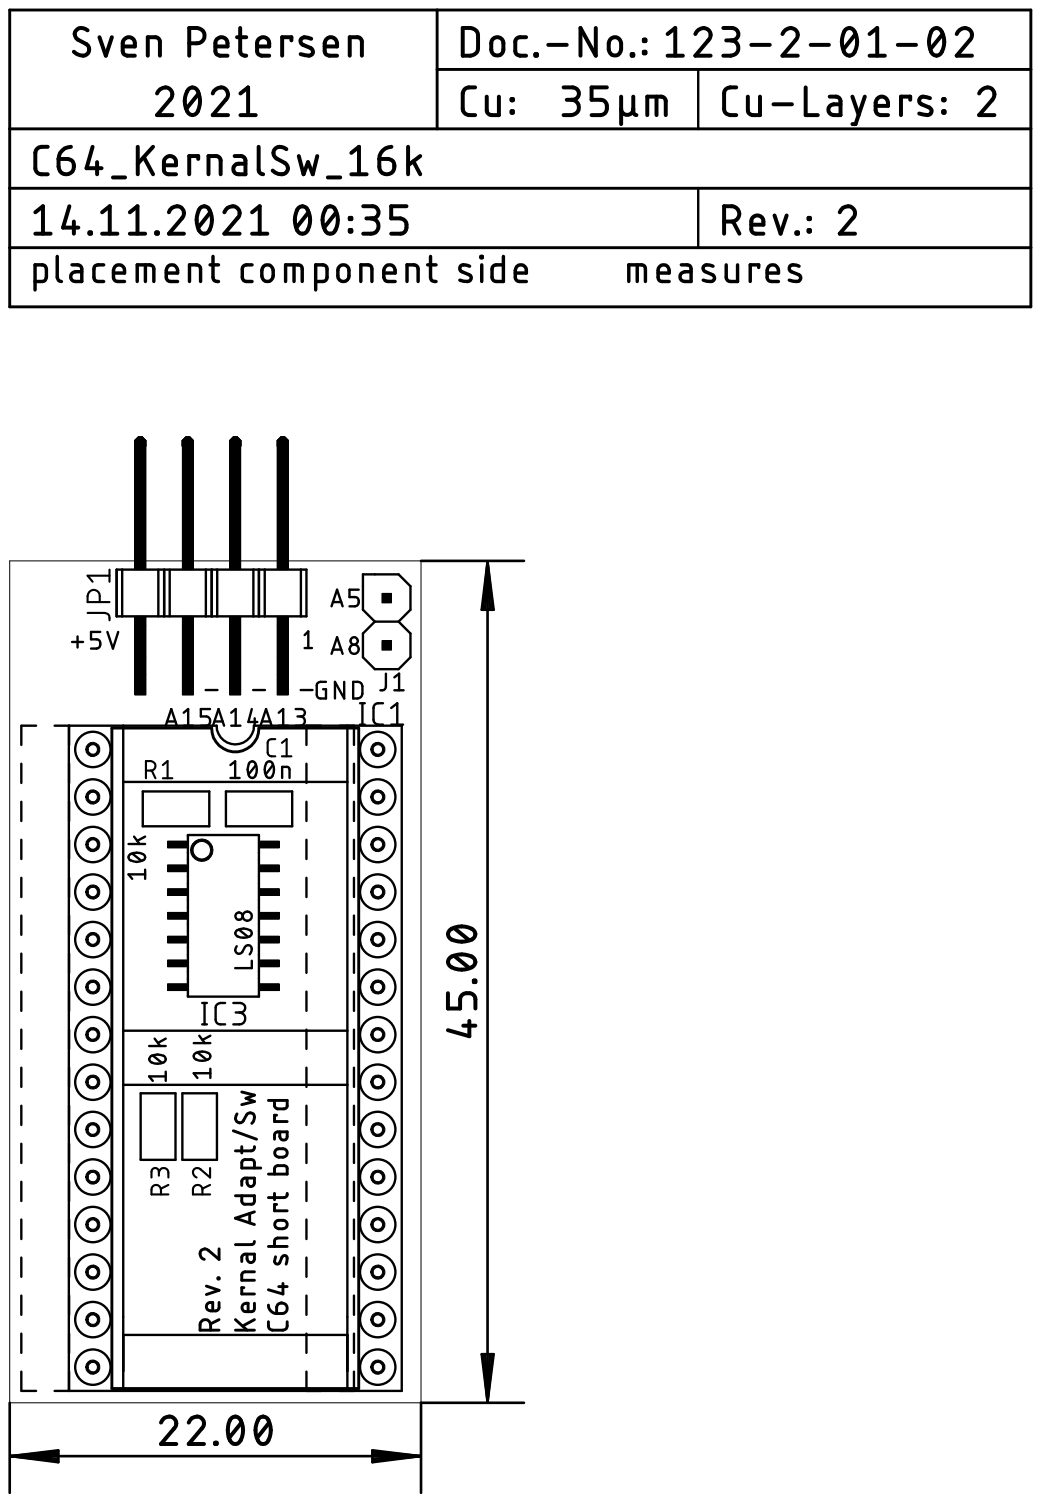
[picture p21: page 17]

C64_KernalSw_16k_Testing.docx | | 25.02.2022 10:37
Drafted by Sven Petersen | Page 1 of 1 | Doc.-No.: 123-6-02-02

### C64 Kernal Adapter/Switch (Short Board) Rev. 2

### Testing

A further testing of Rev. 2 is not required since the changes are marginal. The PCB is in daily use without any problems. The following tests were conducted with Rev. 0.

An image file for programming an EPROM was set up.

8k Block | Addr. Offset | Firmware
#0 | 0x0000 | BASIC

#1 | 0x2000 | Original Kernal

#2 | 0x4000 | JiffyDOS

#3 | 0x6000 | JaffyDOS

#4 | 0x8000 | ExOS v3

#5 | 0xA000 | SpeedDos

#6 | 0xC000 | DolphinDos

#7 | 0xE000 | TurboTape

Table 1: Firmware Setup

A M27C512 EPROM (ST, 100ns) was programmed using a XGecu TL866 II Plus programmer.

The EPROM was inserted into the module, the module was installed in the socket of U4 (BASIC/KERNAL) on an ASSY250469 Rev. 4 mainboard.

The jumper configured: A15 set, A14 set, A13 open.

The C64 was switched on. The commodore kernal booted, different software was loaded and executed: everything seems to be working.

The jumper setting was modified to start one alternative kernal after the other. The kernal all booted and a variety of software loaded and executed without problems.

Finally, the jumpers were configured for JiffyDOS and the C64 was used for a couple of days without any problem.

Conclusion: The C64 Kernal Adapter/switch is fully functional.

Pos. Qty Value Footprint Ref.-No. Comment

1 1 123-2-01-02 2 Layer PCB Rev. 2 2 layer, Cu 35µ, HASL, 45mm x 22mm, 1.6mm FR4

2 1 2x04pin/90° 2X04_90_SERIES

_088

JP1 90° pin header, 2.54mm pitch. E.g. Reichelt MPE 088-2-

008

3 2 Jumper 2.54mm (JP1) Jumpers for address selection (in case it is intended to

jumper the kenal selection)

4 1 100n 0805 C1 Ceramic cap, SMD

5 3 10k 0805 R1, R2, R3 SMD resistor

6 1 two Pinstrip, precision

round pins, cut to 14 pins

length

DIL28_SOCKET (IC2) Precision Round pins mandatory! E.g. Reichelt BKL

10120540 or

10PCS Single Row 40Pin 2.54mm Round Male Pin Header

machined (https://www.ebay.de/itm/10PCS-Single-Row-40Pin-2-54mm-Round-Male-Pin-Header-machined/281821698031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)

7 1 74LS08 SO-14 IC3 SMD, LS family recommended, HCT is probably working,

but not tested

8 1 27C512 DIL28-6 IC1 EPROM 200ns or faster recommended
9 1 DIP28 socket DIL28-6 (IC1) Precision round pin is recommended

## C64 Kernal Adapter/Switch for short boards Rev. 2

## Bill of Material Rev. 2.0

C64_KernalSw_16k_BOM_v2_0.xlsx

Drafted by Sven Petersen Page 1 of 1

25.02.2022 10:40
Doc.No.: 123-5-01-02.0

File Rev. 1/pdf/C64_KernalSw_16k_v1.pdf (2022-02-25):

# Project Documentation

## C64 Kernal Adapter/Switch (Short Board)

## Project number: 123

## Revision: 1

## Date: 17.02.2021

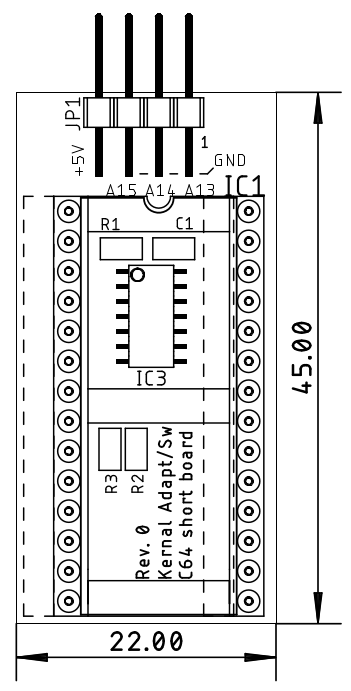
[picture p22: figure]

C64_KernalSw_16k_ModD.docx | | 25.02.2022 10:23
Drafted by Sven Petersen | Page 1 of 7 | Doc.-No.: 123-6-01-01

### C64 Kernal Adapter/Switch (Short Board) Rev. 1

### Module Description

## Introduction

The board serves for adapting the BASIC/KERNAL ROM U4 (type 23128b) to a 27C512 (or 27C256 or 27C128) EPROM. The pin out of both ICs are slightly different and need adaptation. Furthermore, it allows to access (up to 7) different kernals, which can be selected via the pin-header on the module.

This pin-header is connected in a way, that the selection can either be accomplished with standard 2.54mm jumper bridges, DIP-switches, hex-encoding switches or a microcontroller like an Arduino etc.

Signal Pin | Pin Signal
A13 | 1 | 2 | GND
A14 | 3 | 4 | GND
A15 | 5 | 6 | GND
+5V | 7 | 8 | +5V
Table 1: Jumper (JP1) for Bank Selection

The +5V pins are to provide supply voltage to a microcontroller.

## Dimensions

Figure 1: Kernal Adapter/Switch

## Function

The short board (ASSY 250469) stores the BASIC and the KERNAL in the same ROM. Long boards (all earlier ASSYs) have a separate ROM for BASIC.

C64_KernalSw_16k_ModD.docx | | 25.02.2022 10:23
Drafted by Sven Petersen | Page 2 of 7 | Doc.-No.: 123-6-01-01

### The BASIC is located in the C64’s address space between 0xA000 - 0xBFFF, the KERNAL is

located between 0xE000 – 0xFFFF. The highest three address bits have to be taken care to distinguish between BASIC and KERNAL.
Hex Digit | Binary [A15…A12] ROM
AHEX | HLHL | BASIC
BHEX | HLHH | BASIC
EHEX | HHHL | KERNAL
FHEX | HHHH | KERNAL
Table 2: Encoding of the address bits

A15, A13 and A12 are encoded the same was for both the BASIC and the KERNAL. A14 makes the difference. Consulting the schematic of ASSY250469 (Document 252312), A14 of the CPU address bus is connected to A13 (pin 26) of the 16k ROM (U4/23128B). A LOW on A14 will select the lower 8k, a HIGH will select the higher 8k.

This has to be taken care of on the EPROM adapter. A LOW on A13 (which is connected to A14 of the CPU) has to select the lowest (BASIC) 8k block, a HIGH is addressing the (KERNAL) 8k memory block, which is selected by the jumper JP1. The trick is done with three AND gates (IC3). The
outputs are connected to A13 … A15 of the EPROM. One input of each one is connected to pin
26 of the socket U4. In case this is LOW (BASIC selected) the output of all three gates is LOW, too. The lowest 8k memory block of the EPROM is selected. In case pin 26 is HIGH, the configuration set on JP1 appears at the output of the AND gates. This way, the selected 8k memory block of the EPROM is addressed.

## Bank Selection

The desired KERNAL is selected at JP1. For the pinout refer to Table 1. The jumper is installed (vertically) in a way, that it connects the address line with the GND potential.

A15 | A14 | A13 | 8k Block | Addr. Offset
set | set | set | illegal | 0x0000
set | set | open | #1 | 0x2000
set | open | set | #2 | 0x4000
set | open | open | #3 | 0x6000
open | set | set | #4 | 0x8000
open | set | open | #5 | 0xA000
open | open | set | #6 | 0xC000
open | open | open | #7 | 0xE000
Table 3: Selection of EPROM memory blocks

A set jumper corresponds to a LOW level (binary 0), an open jumper to a HIGH level. Do not confuse the C64 memory address and the EPROM memory address. They have the address Bit A0 to A12 in common, but the rest is different. Each of the 8k blocks appears between address $E000 and $FFFF of the C64. The setting marked illegal selects the lowest 8k, which are reserved for the BASIC. Do not use more than two jumpers to prevent this.


C64_KernalSw_16k_ModD.docx | | 25.02.2022 10:23
Drafted by Sven Petersen | Page 3 of 7 | Doc.-No.: 123-6-01-01

## Sources for BASIC and KERNAL

The content of the BASIC ROM and the KERNAL ROM can be found here:

http://www.zimmers.net/anonftp/pub/cbm/firmware/computers/c64/index.html (64c.251913-01.bin) (http://www.zimmers.net/anonftp/pub/cbm/firmware/computers/c64/64c.251913-01.bin)

This file includes the BASIC and the original KERNAL and have to be loaded to the lowest 16k of the EPROM. In case it is not desired to load the original KERNAL to 8k-Block #1, this memory block can be overwritten.

Separate BASIC and KERNAL ROMs and Scandinavian KERNAL ROMs can be found at the URL mentioned before or can alternatively be obtained from the Emulator Software VICE (C64/basic and C64/kernal).

Alternative kernals can be found elsewhere on internet. A reliable source is

https://csdb.dk/

The popular JiffyDOS is still a commercial product and can be acquired for little money from

http://www.go4retro.com/

JaffyDOS is a patch for JiffyDOS. The patch program can be obtained from World of Jani:

http://blog.worldofjani.com

## Setting up an EPROM image

Combining the desired ROM (*.bin) files to one programming image works with the software of the programmer. This might a different with different model. Here it is demonstrated using the popular TL866. In case the programmer software does not provide the function, a Hex Editor like HxD will do the job.

First, the BASIC ROM has to be loaded into the buffer. This works like always:

File → Open → Select the BASIC ROM

Use default file load options (Figure 2):

Figure 2: Default load options, clear buffer with default
Now the BASIC is loaded. It will occupy the addresses 0000 – 1FFF.


C64_KernalSw_16k_ModD.docx | | 25.02.2022 10:23
Drafted by Sven Petersen | Page 4 of 7 | Doc.-No.: 123-6-01-01

Figure 3: Buffer content after BASIC was loaded

The buffer above 1FFF is still empty (filled with FF, Figure 3).

The KERNAL has to be loaded to the next free 8k memory block in the buffer. Please refer to Table
3. Further, it is important, not to clear the buffer. Otherwise, the BASIC will be lost and the EPROM will not work. Refer to Figure 4.

Figure 4: Load options for the first KERNAL

Clear Buffer when loading file is disabled, the address for the first kernal is 2000HEX

Repeat this procedure with the appropriate buffer/EPROM address, until all desired kernals are in the buffer. Store the buffer for later use, insert a blank EPROM and program it. Insert it in the Kernal Adapter/Switch.

## Adding More Kernals to an Already programmed EPROM

In case the unused 8k memory slots of the EPROM are filled with FF, it is still possible to program additional kernel images without erasing them before. FF is the content of an empty byte in an EPROM. It is possible to alter such a byte to every other byte content. Before the new memory is written, the prior content can be read into the program buffer, then a free 8k slot is determined and the kernel is loaded into that slot. Refer to chapter “Setting up an EPROM image”. Now, the


C64_KernalSw_16k_ModD.docx | | 25.02.2022 10:23
Drafted by Sven Petersen | Page 5 of 7 | Doc.-No.: 123-6-01-01

buffer content can be programmed. It is possible to program the complete buffer, the bytes already programmed will (usually) not be corrupted and after programming, the EPROM will verify ok.

## Installation

Possibly, the BASIC/Kernal ROM (U4) has to be unsoldered and a socket (preferably round pin precision contacts) has to be installed, before the Kernal Adapter/Switch can be installed on ASSY250469. The notch of the EPROM is pointing towards the user port, when installed properly (Figure 5).

Figure 5: Installation of the Kernal Adapter/Switch

Usually, the board fits above the components placed next to U4, maybe those have to be bent backwards a bit. Prevent that the resistor touches the pin header of the adapter under all circumstances.

Figure 6: Parts under the adapter board

## Compatibility of EPROMs

It is recommended to use 27C512 EPROMs only. The smaller EPROM Types 27C256 and 27C128 might conflict with accessing the BASIC 8k slot. The unused address signals will be tied

C64_KernalSw_16k_ModD.docx | | 25.02.2022 10:23
Drafted by Sven Petersen | Page 6 of 7 | Doc.-No.: 123-6-01-01

LOW while this access. This means, that Vpp will be approximately 0V and /PGM will be low. This is a not recommended setting.

27C128
| 27C256
| 27C512
| SOCKET
Vpp | Vpp | A15 | 1 | A15 | VCC | 28 | VCC | VCC | VCC
A12 | A12 | A12 | 2 | A12 | A14 | 27 | A14 | A14 | /PGM
A7 | A7 | A7 | 3 | A7 | A13 | 26 | A13 | A13 | A13
A6 | A6 | A6 | 4 | A6 | A8 | 25 | A8 | A8 | A8
A5 | A5 | A5 | 5 | A5 | A9 | 24 | A9 | A9 | A9
A4 | A4 | A4 | 6 | A4 | A11 | 23 | A11 | A11 | A11
A3 | A3 | A3 | 7 | A3 | /OE | 22 | /G/Vpp | /G | /G
A2 | A2 | A2 | 8 | A2 | A10 | 21 | A10 | A10 | A10
A1 | A1 | A1 | 9 | A1 | GND | 20 | /E | /E | /E
A0 | A0 | A0 | 10 | A0 | D7 | 19 | D7 | D7 | D7
D0 | D0 | D0 | 11 | D0 | D6 | 18 | D6 | D6 | D6
D1 | D1 | D1 | 12 | D1 | D5 | 17 | D5 | D5 | D5
D2 | D2 | D2 | 13 | D2 | D4 | 16 | D4 | D4 | D4
GND | GND | GND | 14 | GND | D3 | 15 | D3 | D3 | D3
Table 4: EPROM pin compatibility

## Startup and Trouble shooting

Before you insert the Kernal Adaptor/Switch into the socket of U4, you should make sure, that there are no fatal failures on it. In the worst case, it will produce a short circuit.

- Check the solder joints on the solder side
- Check the orientation of the socket. The notch is oriented to the side, where the jumper is located
- Make sure, that no jumper is installed horizontally. This could connect GND and VCC, which is a short circuit.
- After inserting the EPROM, check if the notch is at the same side like the notch of the socket. Check all pins are properly seated in the socket and not bent inwards or outwards.

After all these points are correct, nothing really bad can happen to your C64 anymore. If you get a black screen you only have a configuration problem.

- Did you program the EPROM with a proper *.bin file? BASIC and one or more kernals? Maybe check the buffer content of your programmer software again.
- Did you set the address bits A13…A15 correctly? A set (closed) jumper means LOW
- You must not set all jumpers. This would put the BASIC in place of the Kernal, which will not work.

## Revision History

### Rev. 0

Fully working prototype

C64_KernalSw_16k_ModD.docx | | 25.02.2022 10:23
Drafted by Sven Petersen | Page 7 of 7 | Doc.-No.: 123-6-01-01

### Rev. 1

The shape of the solder-pads of JP1 was changed to enable bridging. Pin 10 is not connected to +5V anymore.

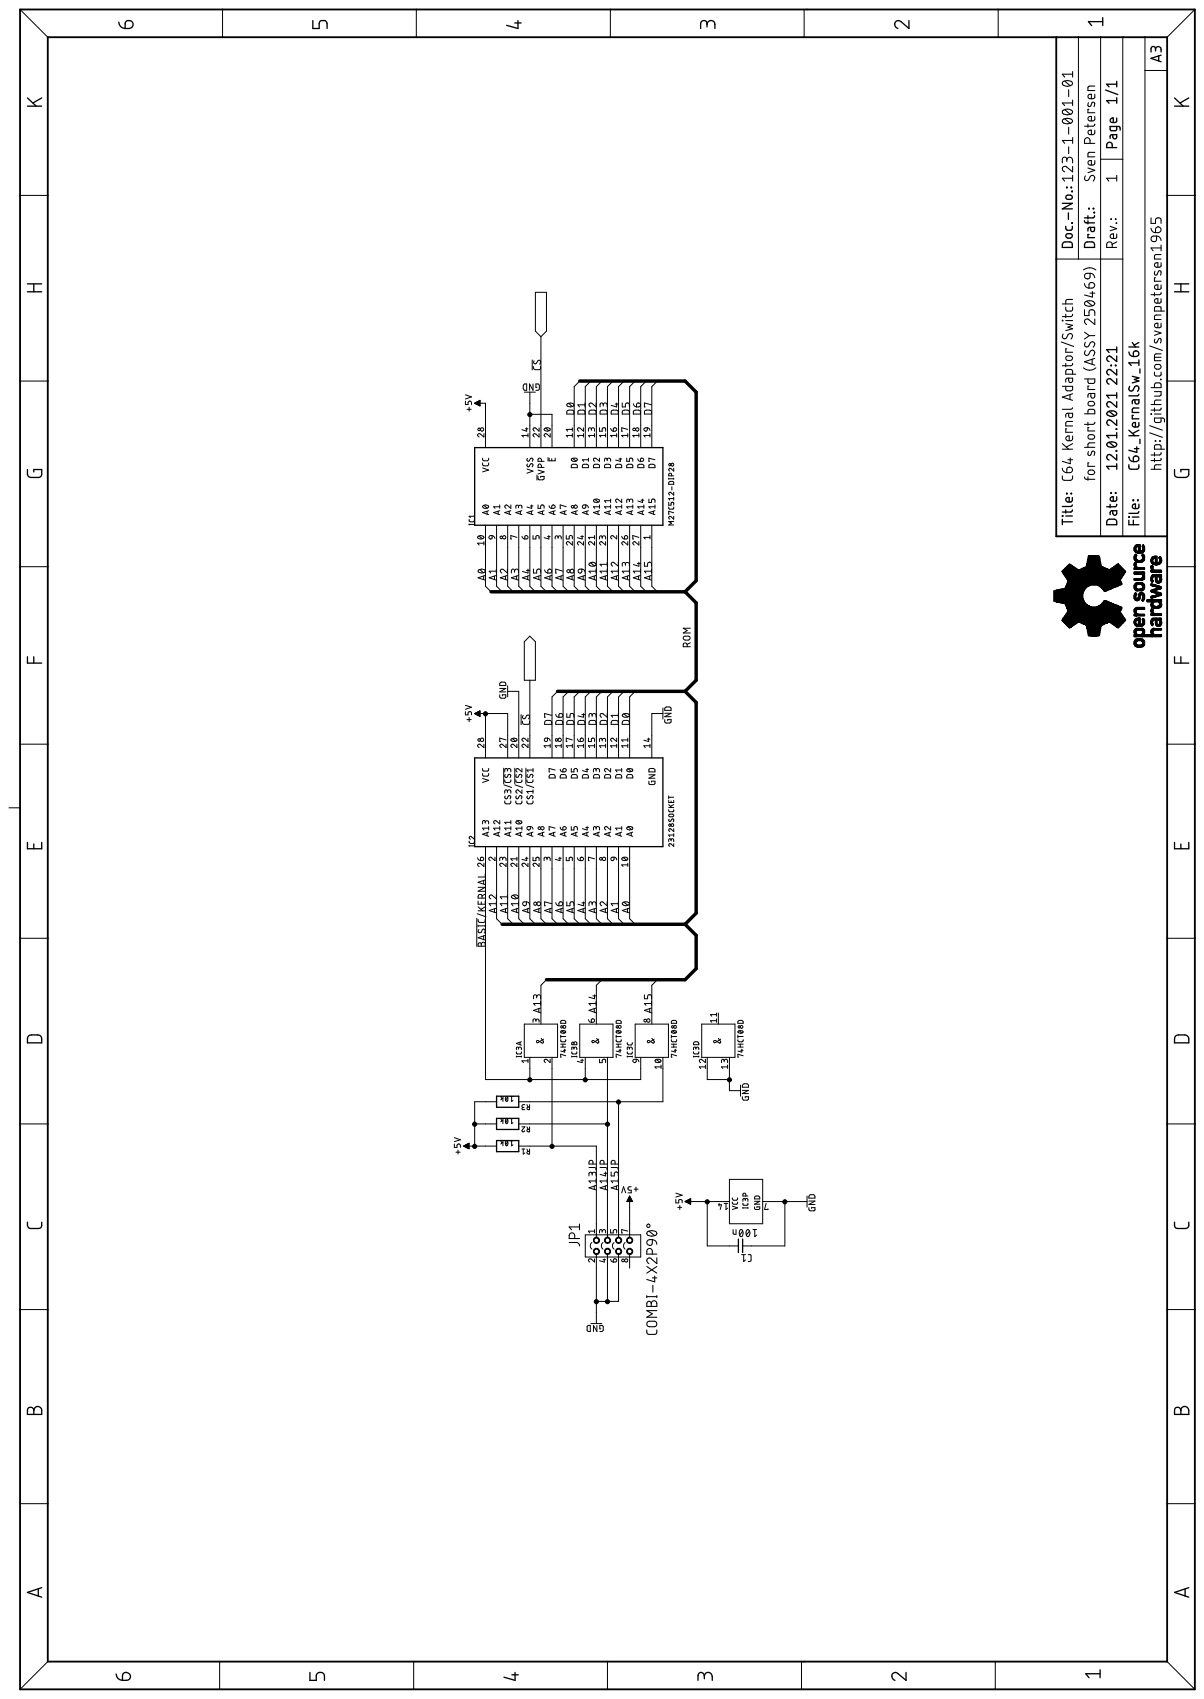
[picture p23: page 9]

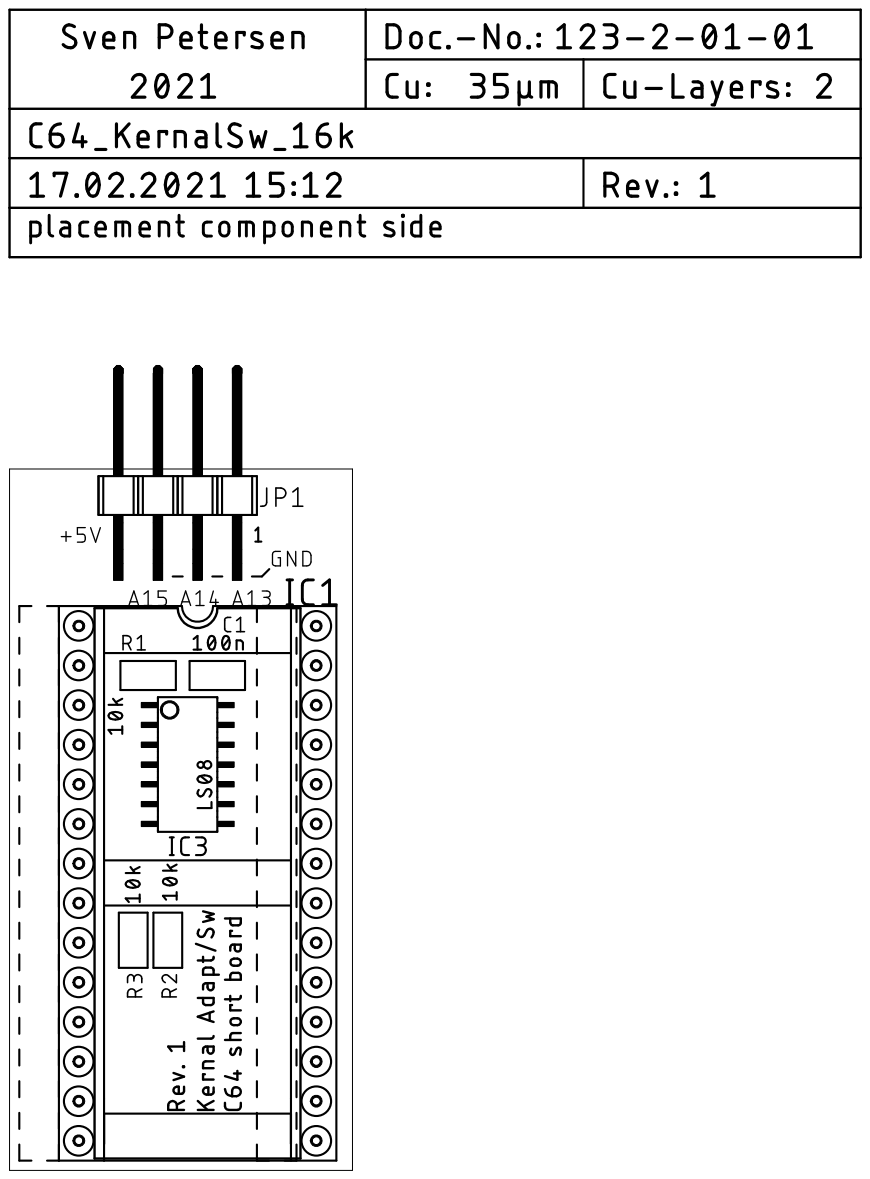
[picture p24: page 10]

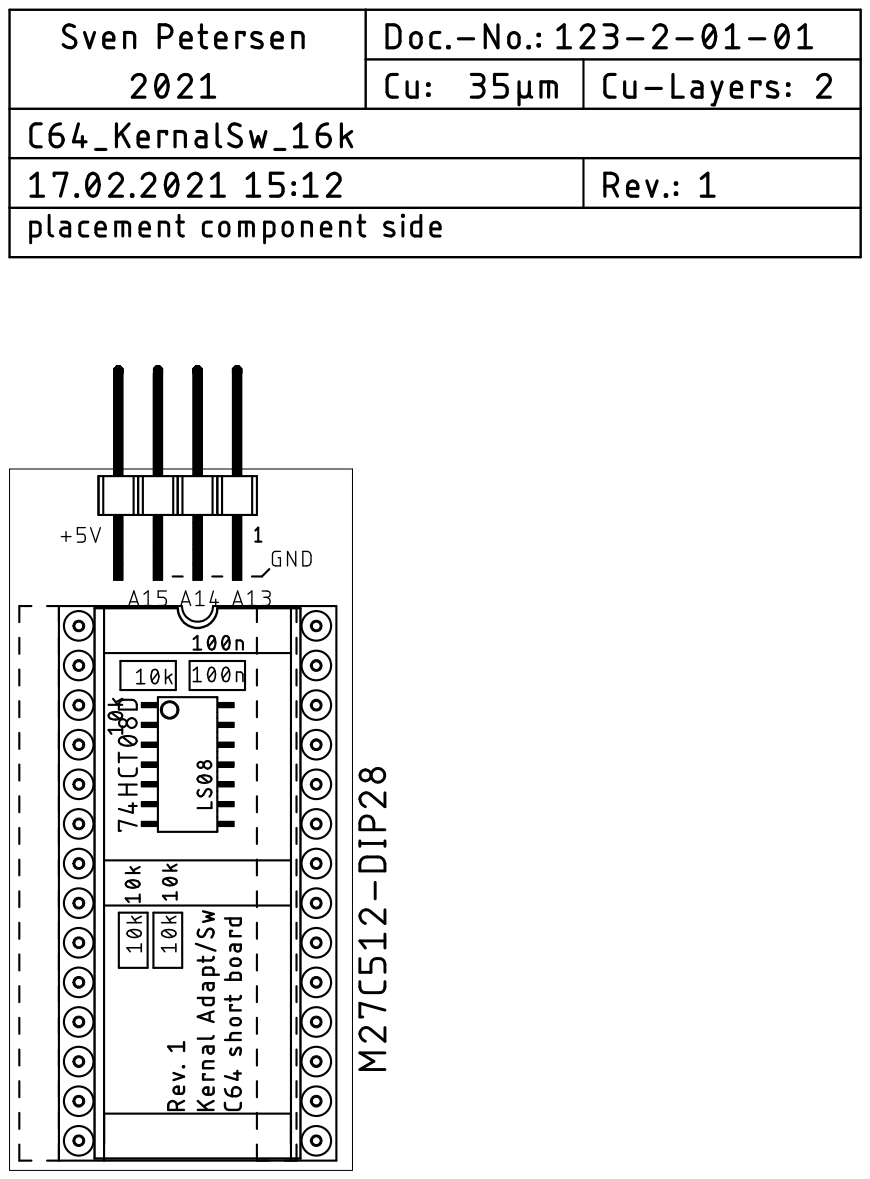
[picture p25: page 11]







C64_KernalSw_16k_Testing.docx | | 25.02.2022 10:24
Drafted by Sven Petersen | Page 1 of 1 | Doc.-No.: 123-6-02-01

### C64 Kernal Adapter/Switch (Short Board) Rev. 1

### Testing

A further testing of Rev. 1 is not required since the changes are marginal. The PCB is in daily use without any problems. The following tests were conducted with Rev. 0.

An image file for programming an EPROM was set up.

8k Block | Addr. Offset | Firmware
#0 | 0x0000 | BASIC

#1 | 0x2000 | Original Kernal

#2 | 0x4000 | JiffyDOS

#3 | 0x6000 | JaffyDOS

#4 | 0x8000 | ExOS v3

#5 | 0xA000 | SpeedDos

#6 | 0xC000 | DolphinDos

#7 | 0xE000 | TurboTape

Table 1: Firmware Setup

A M27C512 EPROM (ST, 100ns) was programmed using a XGecu TL866 II Plus programmer.

The EPROM was inserted into the module, the module was installed in the socket of U4 (BASIC/KERNAL) on an ASSY250469 Rev. 4 mainboard.

The jumper configured: A15 set, A14 set, A13 open.

The C64 was switched on. The commodore kernal booted, different software was loaded and executed: everything seems to be working.

The jumper setting was modified to start one alternative kernal after the other. The kernal all booted and a variety of software loaded and executed without problems.

Finally, the jumpers were configured for JiffyDOS and the C64 was used for a couple of days without any problem.

Conclusion: The C64 Kernal Adapter/switch is fully functional.

Pos. Qty Value Footprint Ref.-No. Comment

1 1 123-2-01-01 2 Layer PCB Rev. 1 2 layer, Cu 35µ, HASL, 45mm x 22mm, 1.6mm FR4

2 1 2x04pin/90° 2X04_90_SERIES

_088

JP1 90° pin header, 2.54mm pitch. E.g. Reichelt MPE 088-2-

008

3 2 Jumper 2.54mm (JP1) Jumpers for address selection (in case it is intended to

jumper the kenal selection)

4 1 100n 0805 C1 Ceramic cap, SMD

5 3 10k 0805 R1, R2, R3 SMD resistor

6 1 two Pinstrip, precision

round pins, cut to 14 pins

length

DIL28_SOCKET (IC2) Precision Round pins mandatory! E.g. Reichelt BKL

10120540 or

10PCS Single Row 40Pin 2.54mm Round Male Pin Header

machined (https://www.ebay.de/itm/10PCS-Single-Row-40Pin-2-54mm-Round-Male-Pin-Header-machined/281821698031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)

7 1 74LS08 SO-14 IC3 SMD, LS family recommended, HCT is probably working,

but not tested

8 1 27C512 DIL28-6 IC1 EPROM 200ns or faster recommended
9 1 DIP28 socket DIL28-6 (IC1) Precision round pin is recommended

## C64 Kernal Adapter/Switch for short boards Rev. 1

## Bill of Material Rev. 1.0

C64_KernalSw_16k_BOM_v1_0.xlsx

Drafted by Sven Petersen Page 1 of 1

25.02.2022 10:26
Doc.No.: 123-5-01-01.0

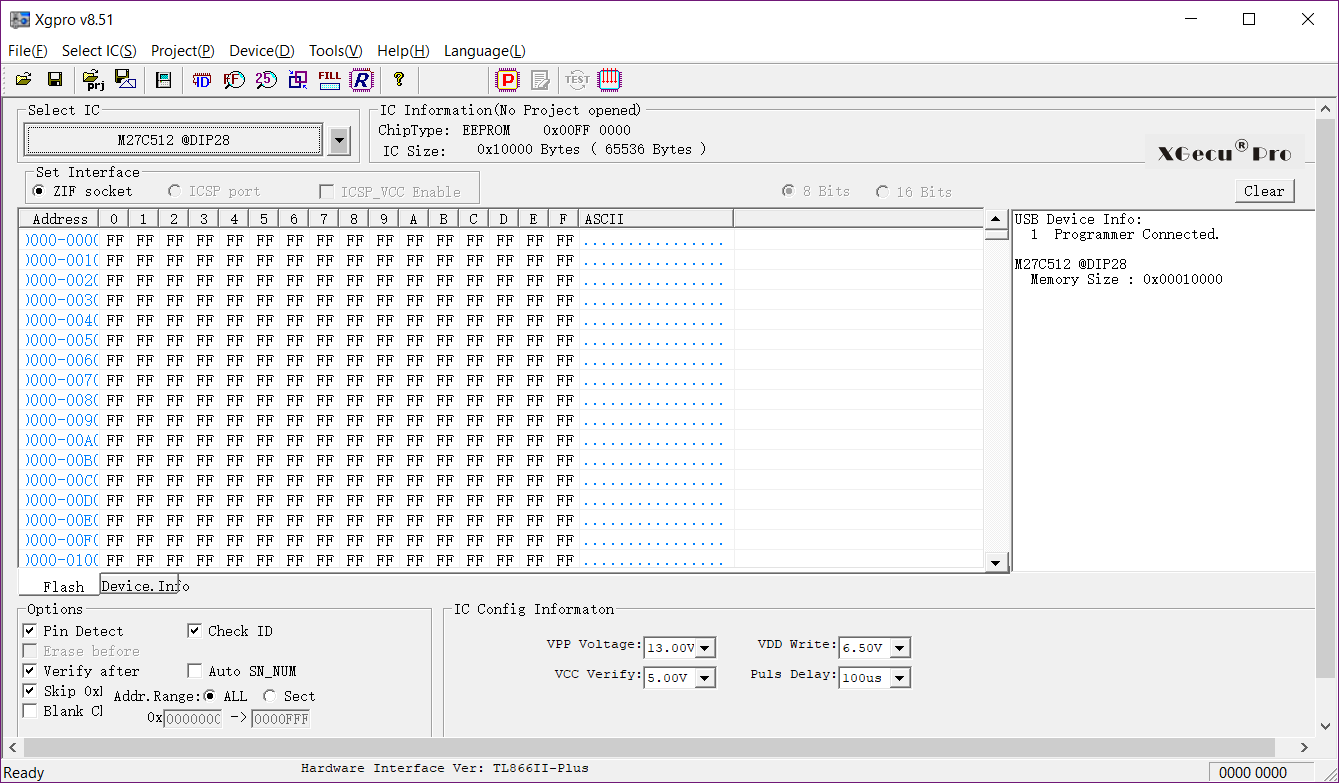
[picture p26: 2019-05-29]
Rev. 2/pictures/Xgpro_empty.png

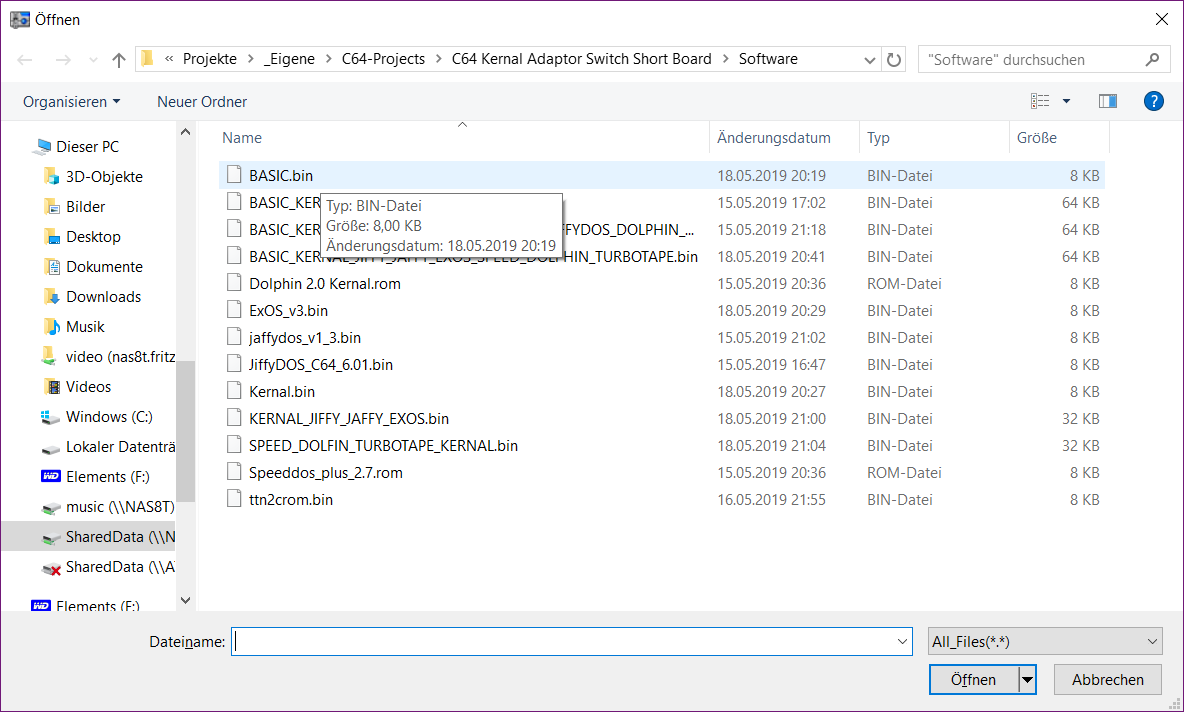
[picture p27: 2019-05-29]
Rev. 2/pictures/Xgpro_file.png

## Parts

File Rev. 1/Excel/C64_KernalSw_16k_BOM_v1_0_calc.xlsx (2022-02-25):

C64 Kernal Adapter/Switch for short boards Rev. 1
Bill of Material Rev. 1.0
Pos. | Qty | Value | €/ea | € | Comment
1 | 1 | 123-2-01-00 | 1.00 € | 1.00 € | 2 layer, Cu 35µ, HASL, 45mm x 22mm, 1.6mm FR4
2 | 1 | 2x04pin/90° | 0.27 € | 0.27 € | 90° pin header, 2.54mm pitch. E.g. Reichelt MPE 088-2-008
3 | 3 | Jumper | 0.02 € | 0.06 € | Jumpers for address selection (in case it is intended to jumper the kenal selection)
4 | 1 | 100n | 0.07 € | 0.07 € | Ceramic cap, SMD
5 | 3 | 10k | 0.02 € | 0.06 € | SMD resistor
6 | 1 | two Pinstrip, precision round pins, cut to 14 pins length | 1.99 € | 1.99 € | Precision Round pins mandatory! E.g. Reichelt BKL 10120540 or
 |  |  |  | 0.00 € | 10PCS Single Row 40Pin 2.54mm Round Male Pin Header machined (https://www.ebay.de/itm/10PCS-Single-Row-40Pin-2-54mm-Round-Male-Pin-Header-machined/281821698031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)
7 | 1 | 74LS08 | 1.00 € | 1.00 € | SMD, LS family recommended, HCT is probably working, but not tested
8 | 1 | 27C512 | 0.00 € | 0.00 € | EPROM 200ns or faster recommended
9 | 1 | DIP28 socket | 0.43 € | 0.43 € | Precision round pin is recommended
10 |  |  | Summe | 4.88 €

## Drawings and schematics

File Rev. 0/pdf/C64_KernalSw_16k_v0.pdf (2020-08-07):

# Project Documentation

## C64 Kernal Adapter/Switch (Short Board)

## Project number: 123

## Revision: 0

## Date: May the 4th

, 2019


C64_KernalSw_16k_ModD.docx | | 29.05.2019 11:33
Drafted by Sven Petersen | Page 1 of 6 | Doc.-No.: 123-6-01-00

### C64 Kernal Adapter/Switch (Short Board) Rev. 0

### Module Description

## Introduction

The board serves for adapting the BASIC/KERNAL ROM U4 (type 23128b) to a 27C512 (or 27C256 or 27C128) EPROM. The pin out of both ICs are slightly different and need adaptation. Furthermore, it allows to access (up to 7) different kernals, which can be selected via the pin-header on the module.

This pin-header is connected in a way, that the selection can either be accomplished with standard 2.54mm jumper bridges, DIP-switches, hex-encoding switches or a microcontroller like an Arduino etc.

Signal Pin | Pin Signal
A13 | 1 | 2 | GND
A14 | 3 | 4 | GND
A15 | 5 | 6 | GND
+5V | 7 | 8 | +5V
Table 1: Jumper (JP1) for Bank Selection

The +5V pins are to provide supply voltage to a microcontroller.

## Dimensions

Figure 1: Kernal Adapter/Switch

## Function

The short board (ASSY 250469) stores the BASIC and the KERNAL in the same ROM. Long boards (all earlier ASSYs) have a separate ROM for BASIC.

C64_KernalSw_16k_ModD.docx | | 29.05.2019 11:33
Drafted by Sven Petersen | Page 2 of 6 | Doc.-No.: 123-6-01-00

### The BASIC is located in the C64’s address space between 0xA000 - 0xBFFF, the KERNAL is

located between 0xE000 – 0xFFFF. The highest three address bits have to be taken care to distinguish between BASIC and KERNAL.
Hex Digit | Binary [A15…A12] ROM
AHEX | HLHL | BASIC
BHEX | HLHH | BASIC
EHEX | HHHL | KERNAL
FHEX | HHHH | KERNAL
Table 2: Encoding of the address bits

A15, A13 and A12 are encoded the same was for both the BASIC and the KERNAL. A14 makes the difference. Consulting the schematic of ASSY250469 (Document 252312), A14 of the CPU address bus is connected to A13 (pin 26) of the 16k ROM (U4/23128B). A LOW on A14 will select the lower 8k, a HIGH will select the higher 8k.

This has to be taken care of on the EPROM adapter. A LOW on A13 (which is connected to A14 of the CPU) has to select the lowest (BASIC) 8k block, a HIGH is addressing the (KERNAL) 8k memory block, which is selected by the jumper JP1. The trick is done with three AND gates (IC3). The
outputs are connected to A13 … A15 of the EPROM. One input of each one is connected to pin
26 of the socket U4. In case this is LOW (BASIC selected) the output of all three gates is LOW, too. The lowest 8k memory block of the EPROM is selected. In case pin 26 is HIGH, the configuration set on JP1 appears at the output of the AND gates. This way, the selected 8k memory block of the EPROM is addressed.

## Bank Selection

The desired KERNAL is selected at JP1. For the pinout refer to Table 1. The jumper is installed (vertically) in a way, that it connects the address line with the GND potential.

A15 | A14 | A13 | 8k Block | Addr. Offset
set | set | set | illegal | 0x0000
set | set | open | #1 | 0x2000
set | open | set | #2 | 0x4000
set | open | open | #3 | 0x6000
open | set | set | #4 | 0x8000
open | set | open | #5 | 0xA000
open | open | set | #6 | 0xC000
open | open | open | #7 | 0xE000
Table 3: Selection of EPROM memory blocks

A set jumper corresponds to a LOW level (binary 0), an open jumper to a HIGH level. Do not confuse the C64 memory address and the EPROM memory address. They have the address Bit A0 to A12 in common, but the rest is different. Each of the 8k blocks appears between address $E000 and $FFFF of the C64. The setting marked illegal selects the lowest 8k, which are reserved for the BASIC. Do not use more than two jumpers to prevent this.


C64_KernalSw_16k_ModD.docx | | 29.05.2019 11:33
Drafted by Sven Petersen | Page 3 of 6 | Doc.-No.: 123-6-01-00
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

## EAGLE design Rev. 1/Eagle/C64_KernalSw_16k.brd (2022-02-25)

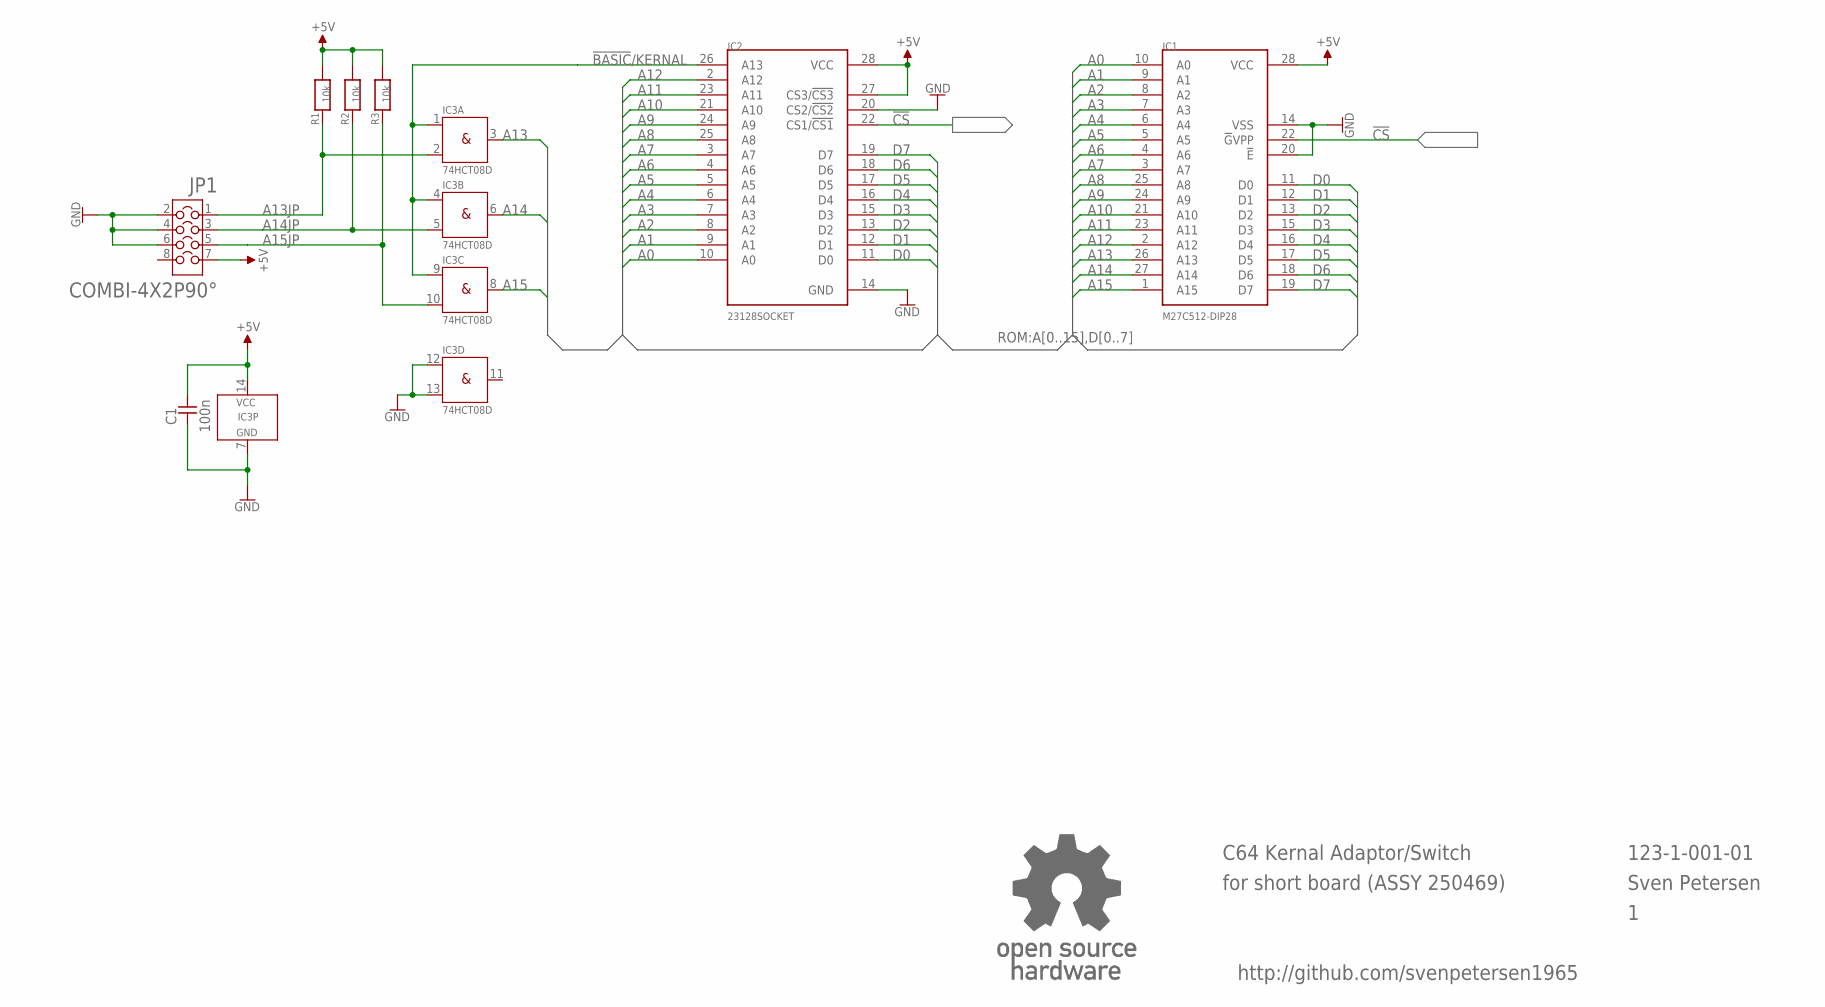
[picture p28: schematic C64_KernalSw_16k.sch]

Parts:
C1: 100n; 0805
IC1: M27C512-DIP28; DIL28-6
IC2: 23128SOCKET; DIL28_SOCKET
IC3: 74HCT08D; SO-14
JP1: COMBI-4X2P90°; COMBI-4X2-90
R1, R2, R3: 10k; 0805
U$21: OPEN_SOURCE_HW; OPENHW

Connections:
!BASIC!/KERNAL: IC2.26 (A13), IC3.1 (I0), IC3.4 (I0), IC3.9 (I0)
!CS: IC1.22 (!G!VPP), IC2.22 (CS1/!CS1)
+5V: C1.2, IC1.28 (VCC), IC2.27 (CS3/!CS3), IC2.28 (VCC), IC3.14 (VCC), JP1.7, R1.2, R2.2, R3.2
A0: IC1.10 (A0), IC2.10 (A0)
A1: IC1.9 (A1), IC2.9 (A1)
A2: IC1.8 (A2), IC2.8 (A2)
A3: IC1.7 (A3), IC2.7 (A3)
A4: IC1.6 (A4), IC2.6 (A4)
A5: IC1.5 (A5), IC2.5 (A5)
A6: IC1.4 (A6), IC2.4 (A6)
A7: IC1.3 (A7), IC2.3 (A7)
A8: IC1.25 (A8), IC2.25 (A8)
A9: IC1.24 (A9), IC2.24 (A9)
A10: IC1.21 (A10), IC2.21 (A10)
A11: IC1.23 (A11), IC2.23 (A11)
A12: IC1.2 (A12), IC2.2 (A12)
A13: IC1.26 (A13), IC3.3 (O)
A13JP: IC3.2 (I1), JP1.1, R1.1
A14: IC1.27 (A14), IC3.6 (O)
A14JP: IC3.5 (I1), JP1.3, R2.1
A15: IC1.1 (A15), IC3.8 (O)
A15JP: IC3.10 (I1), JP1.5, R3.1
D0: IC1.11 (D0), IC2.11 (D0)
D1: IC1.12 (D1), IC2.12 (D1)
D2: IC1.13 (D2), IC2.13 (D2)
D3: IC1.15 (D3), IC2.15 (D3)
D4: IC1.16 (D4), IC2.16 (D4)
D5: IC1.17 (D5), IC2.17 (D5)
D6: IC1.18 (D6), IC2.18 (D6)
D7: IC1.19 (D7), IC2.19 (D7)
GND: C1.1, IC1.14 (VSS), IC1.20 (!E), IC2.14 (GND), IC2.20 (CS2/!CS2), IC3.7 (GND), IC3.12 (I0), IC3.13 (I1), JP1.2, JP1.4, JP1.6

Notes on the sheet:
123-1-001-01
Sven Petersen
C64 Kernal Adaptor/Switch
for short board (ASSY 250469)
http://github.com/svenpetersen1965

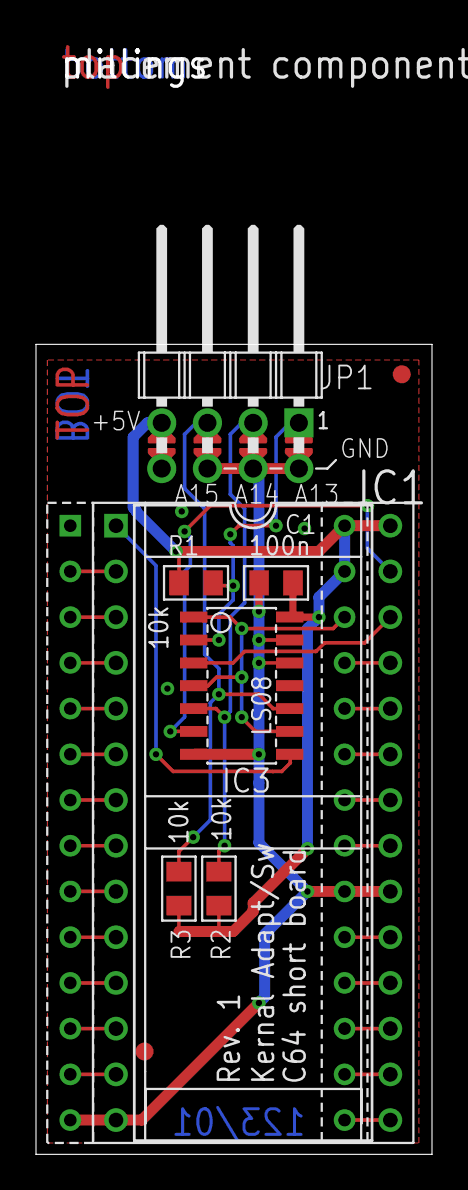
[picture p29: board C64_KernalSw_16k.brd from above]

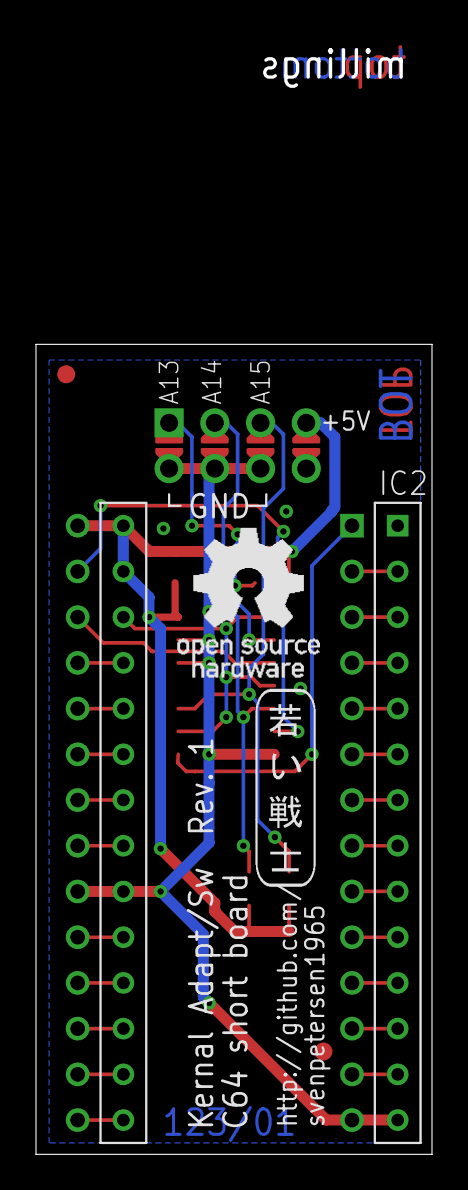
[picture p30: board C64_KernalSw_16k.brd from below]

Board: 2 copper layers, 22.0 x 45.0 mm, 15 parts (2 on the bottom side), 31 nets.

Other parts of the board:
U$16: GS28P
U$17, U$18: SMD_REF_R1MM
U$19: 2LAYER
U$20: PCB-TITLE/
U$22: SVEN_TAG

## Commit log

2020-06-09 BOM calculation added
    prices of June 9th, 2020
    [C64_KernalSw_16k_BOM_v0_0_calc.xlsx]
2020-08-07 Silk Screen Update
    [C64_KernalSw_16k.brd, C64_KernalSw_16k.sch]
2022-02-25 Rev. 1 released
    [C64_KernalSw_16k.brd, C64_KernalSw_16k.sch, C64_KernalSw_16k_BOM_v1_0.xlsx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]
2022-02-25 Rev. 2 released
    [C64_KernalSw_16k_BOM_v2_0.xlsx]
